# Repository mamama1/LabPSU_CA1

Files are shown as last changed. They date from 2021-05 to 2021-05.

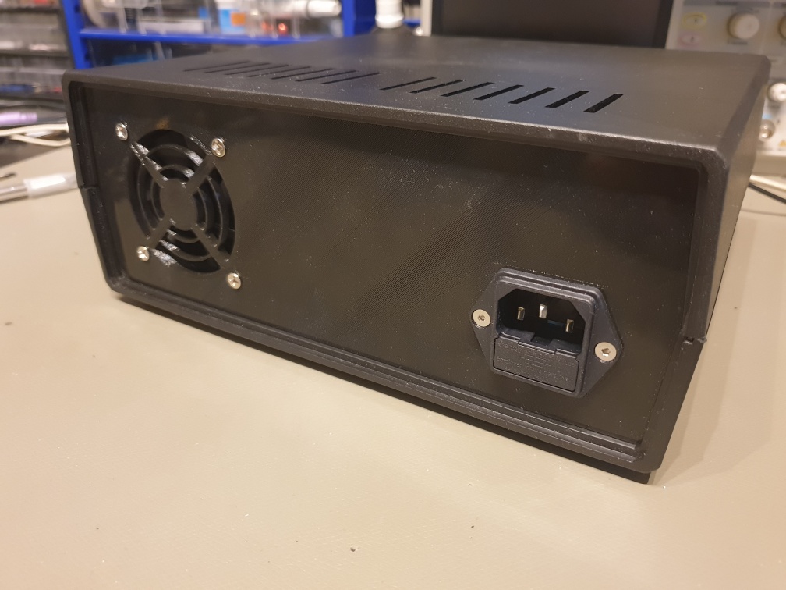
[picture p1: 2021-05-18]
photo_back.jpg

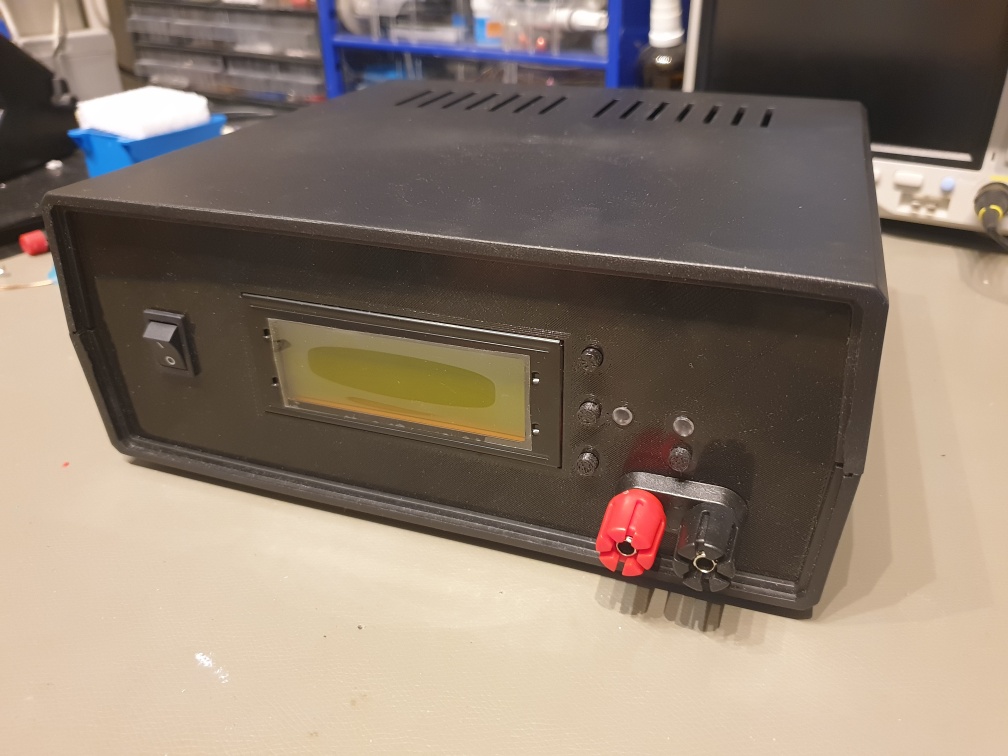
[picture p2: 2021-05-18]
photo_front.jpg

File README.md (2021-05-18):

# LabPSU_CA1
"CheapAss 1" Atmega 1284p controlled LabPSU with basic functionality like CV and CC mode

Welcome to my "CheapAss 1" Lab PSU project, which is based on a TIP3055 power transistor and an Atmega 1284p microcontroller.<br /><br />

Specs:<br />
0 - 24V output voltage in 100 mV steps (CV mode)<br />
0 - 1A output current in 1 mA steps (CC mode)<br />
Around 1% accuracy<br />
Dual 12 Bit DAC (MCP4922)<br />
Precision 4.096V voltage reference for the DAC and Atmega-integrated ADC (MCP1541)<br />
High-side current measurement using the MAX4080F IC<br />
LM324 Quad opamp and LM358 Dual opamp<br />
Low Ripple, Low Noise<br />
One Board solution (transformer onboard)<br />
Front panel for display, buttons, LED and piezo buzzer mounting

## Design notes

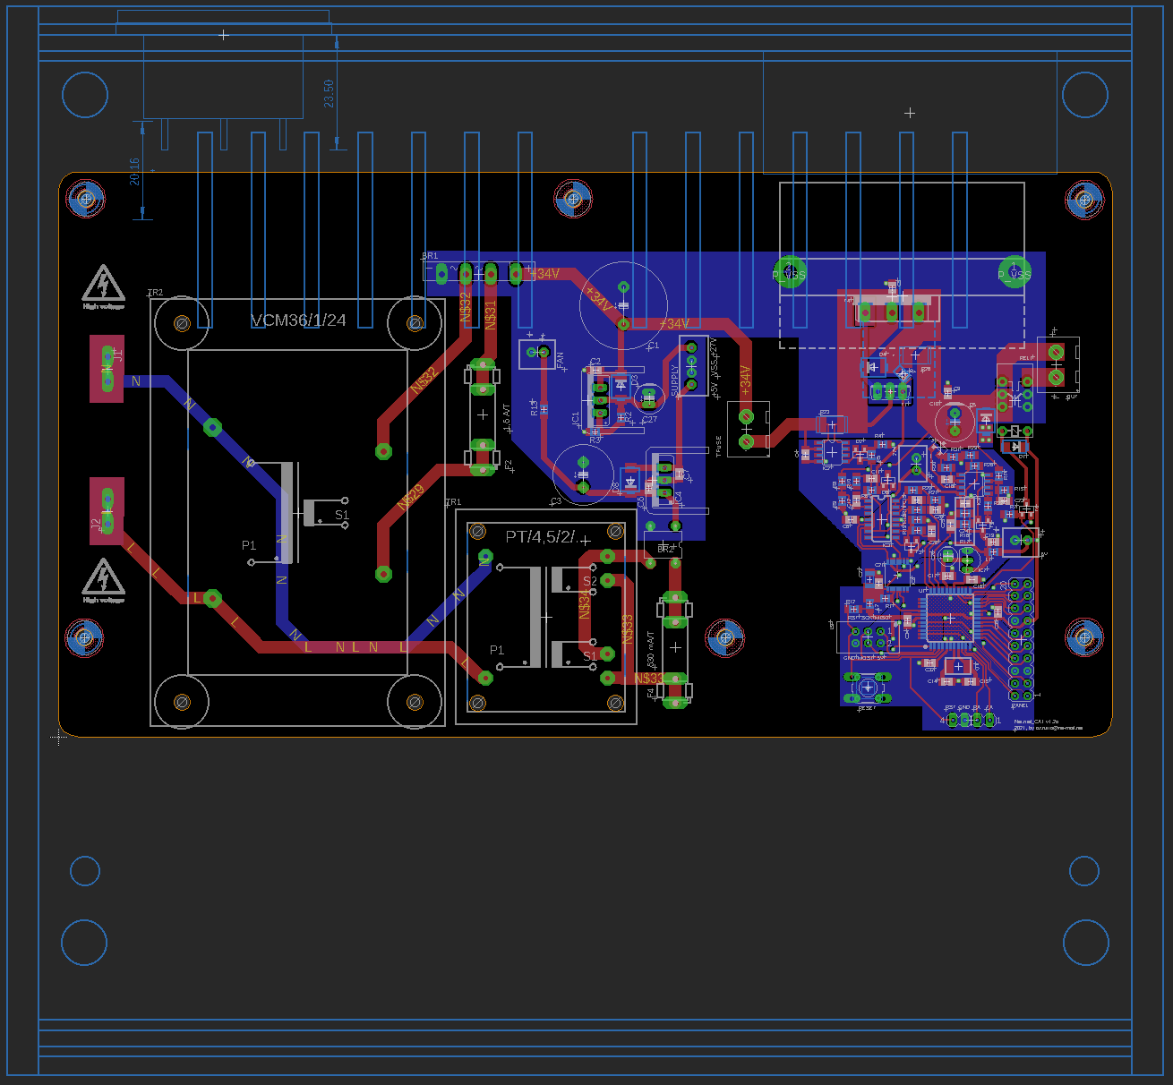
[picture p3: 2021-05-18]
Mainboard/preview.PNG

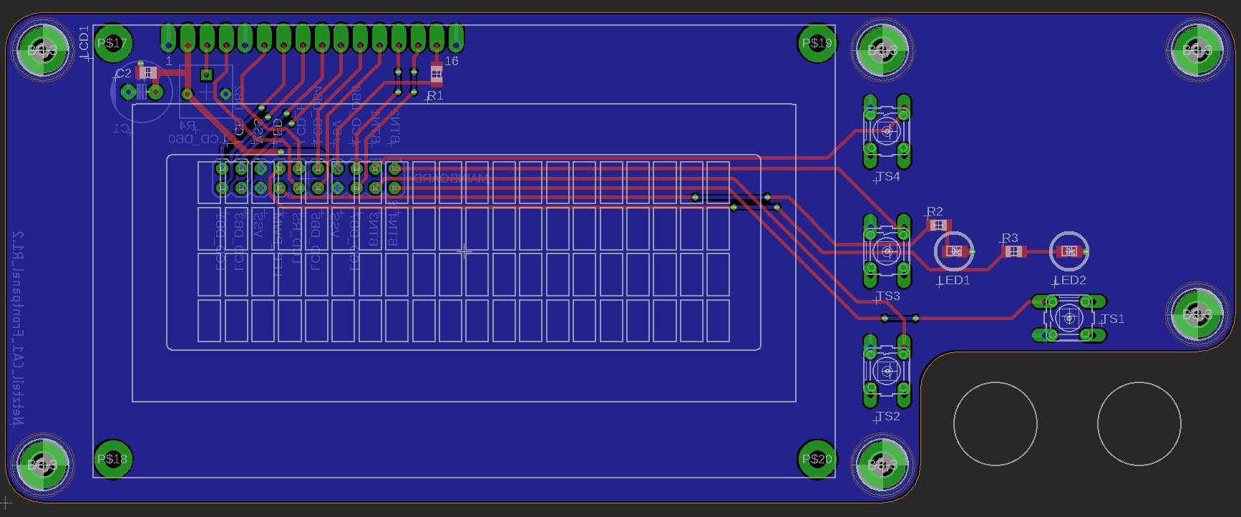
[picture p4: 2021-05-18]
Frontpanel/preview.PNG

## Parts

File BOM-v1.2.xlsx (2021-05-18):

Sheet: BOM-Mainboard
Qty | Value | Parts | OC_CONRAD | OC_CONRAD_ADD | OC_DIGIKEY | OC_MOUSER | OC_MOUSER_ADD | OC_MOUSER_ALT | OC_MOUSER_ALT2_OLD | OC_MOUSER_ALT_OLD | OC_MOUSER_OLD | OC_RS | OC_RS_ADD | OC_RS_ADD2 | REMARKS
1 |  | FAN |  |  | 455-1704-ND |  | 369-MF60251V21UA99 |  |  |  |  |  |  |  | JST-PH Buchse und Lüfter
2 |  | 5V, 27V |  |  | 455-1704-ND
1 |  | SUPPLY |  |  | 455-1706-ND
1 |  | OUT |  |  |  | 710-691311500002 | 565-6883 |  |  |  |  |  |  |  | Printklemme und Schraubklemme für Frontpanel
1 |  | TFUSE |  |  |  | 710-691311500002 |  |  |  |  |  |  | 712-7284 |  | Printklemme und Thermosicherung
1 |  | SERIAL |  |  |  | 200-TSW10407TS
1 |  | PANEL |  |  |  | 200-TSW10707FD |  |  |  |  |  | 289-9896 | 832-3516 |  | Stiftleiste, IDC Stecker und IDC Flachbandkabel
1 |  | ISP |  |  |  | 200-TSW10307TD
1 |  | RESET |  |  |  | 653-B3F-1022
1 | 0.1R 5% 3W 100ppm | R26 |  |  |  | 652-CRA2512FZR100ELF
1 | 0.2R 1% 50ppm | R23 |  |  |  | 756-LRMAP2512R20FT4
1 | 1 A/T | F4 |  |  |  | 693-0751.0110
1 | 1,6 A/T | F2 |  |  |  | 693-0751.0110
1 | 100R 1% 1/4W | R13 |  |  |  | 660-RK73H2ATTD75R0F
9 | 100n/16V | C16, C17, C19, C21, C23, C28, C32, C33, C34 |  |  |  | 810-C2012X7R2A104K
6 | 100n/50V | C2, C4, C7, C8, C9, C24 |  |  |  | 810-C2012X7R2A104K
1 | 100µ/50V | C10 |  |  |  | 667-EEU-FR1H101
1 | 10R 0.5% 25 ppm 1/10W | R31 |  |  |  | 660-RN732ATTD10R0D25 |  | 279-2-1625868-7
5 | 10k 5% 1/10W | R1, R5, R7, R12, R22 |  |  |  | 652-CR0805-JW-103ELF
2 | 10n/16V | C25, C26 |  |  |  | 80-C0805C103K1R
1 | 10n/50V | C11 |  |  |  | 80-C0805C103K1R
1 | 10µ/16V | C20 |  |  |  | 647-USV1C100MFD1TP
1 | 10µ/16V | C22 |  |  |  | 963-TMK316AB7106KL-T
1 | 12k 0.5% 1/10W 25ppm | R8 |  |  |  | 754-RR1220P-123D
3 | 14.7k 0.5% 1/10W 25ppm | R14, R20, R28 |  |  |  | 754-RR1220P-1472D-M |  |  |  |  | 754-RR1220P-123D | 708-6470
1 | 16MHz | Q1 |  |  |  | 717-7A-16.000MAAJ-T
1 | 178R 0.5% 1/10W 25ppm | R29 |  |  |  | 754-RR1220P-1780D-M |  |  | 667-ERA-6AEB1470V | 754-RR1220P-151D | 754-RR1220P-1470D-M | 708-9340
1 | 1k 0.5% 50 ppm 1/10W | R30 |  |  |  | 754-RR1220P-102D
2 | 1n/50V | C13, C18 |  |  |  | 603-CC805KRX7R0BB102
2 | 2.8k 0.5% 1/10W 25ppm | R15, R21 |  |  |  | 754-RR1220P-2801D-M |  |  |  |  | 754-RR1220P-242D | 708-6250
1 | 2200µ/25V | C3 |  |  |  | 667-EEU-FS1E222
3 | 22pF/50V C0G | C12, C14, C15 |  |  |  | 603-CC805JRNPO9BN220
1 | 240R 1% 1/10W | R2 |  |  |  | 652-CR0805FX-2400ELF
1 | 3300µ/50V | C1 |  |  |  | 667-EEU-HD1H332 |  | 647-UVZ1H332MHD
2 | 330n/50V | C5, C6 |  |  |  | 80-C0805C334K5RECTU
1 | 3k 0.5% 1/10W 25ppm | R9 |  |  |  | 754-RR1220P-302D
6 | 4.7k 5% 1/10W | R4, R11, R16, R17, R18, R19 |  |  |  | 652-CR0805-JW-472ELF
1 | 47k 1% 1/10W | R10 |  |  |  | 652-CR0805FX-4702ELF
1 | 47µ/50V | C27 |  |  |  | 667-EEU-FR1H470
1 | 4k7 1% 1/10W | R6 |  |  |  | 652-CR0805FX-1001ELF
1 | 5k1 1% 1/10W | R3 |  |  |  | 652-CR0805FX-5101ELF
1 | 7805TV | IC4 |  |  |  | 511-L7805CV
1 | ATMEGA1284P-AU-TQFP44 | U1 |  |  |  | 556-ATMEGA1284P-AU
2 | BAT54FILMY | D2, D6 |  |  |  | 511-BAT54FILMY
2 | BC847ALT1G | T2, T3 |  |  |  | 863-BC847ALT1G
1 | BD139 | T1 |  |  |  | 511-BD139-10
4 | CGRB307-G | D3, D4, D5, D8 |  |  |  | 750-CGRB307-G
1 | CR201-50VE | HS1 |  |  |  | 588-CR201-50VE | 567-CD-02-05-247-N |  |  |  |  |  |  |  | Kühlkörper und Silpad
2 | D01S | HS2, HS3 |  |  |  | 532-576802B00
1 | DF04M | BR2 |  |  |  | 621-DF04M |  | 512-DF04M
2 | FASTON4.8X0.8 | J1, J2 | 736079 | 1022092 |  |  |  |  |  |  |  |  |  |  | Flachsteckhülsen und Lötstifte
1 | GBU4 | BR1 |  |  |  | 833-GBU4JL-BP
1 | LM317T | IC1 |  |  |  | 511-LM317T
1 | LM324 | IC3 |  |  |  | 595-LM324ADR
1 | LM358 | IC9 |  |  |  | 595-LM358ADR
1 | MAX4080F | IC2 |  |  |  | 700-MAX4080FASA
1 | MCP1541 | IC7 |  |  |  | 579-MCP1541ITO
1 | MCP4922 | IC8 |  |  |  | 579-MCP4922T-E/ST
1 | MOUNT-HOLE3.2 | H2 |  |  |  |  |  |  |  |  |  | 184-2740 | 291-379 | 161-3689 | Nylonschraube, Nylonmutter und Kunststoff-Abstandshalter
5 | MOUNT-HOLE3.2 | H1, H5, H6, H8, H9 |  |  |  |  |  |  |  |  |  | 546-5604
2 | MPZ2012S601AT000 | L1, L2 |  |  |  | 810-MPZ2012S601AT000
2 | PMV130ENEAR | T5, T6 |  |  |  | 771-PMV130ENEAR
1 | PT 4.5/2/8 | TR1 |  |  |  |  |  |  |  |  |  | 201-8463 | 546-5604 |  | Trafo und selbstschneidende Schrauben
1 | S1K | D1 |  |  |  | 512-S1K
1 | SS1FN6-M3/H | D7 |  |  |  | 78-SS1FN6-M3/H
1 | TIP3055 | T4 |  |  |  | 863-TIP3055G
1 | TX2-5V | REL1 |  |  |  | 769-TX2-5V
1 | VCM 36/1/24 | TR2 |  |  |  |  |  |  |  |  |  | 732-0506

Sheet: BOM-Frontpanel
Qty | Value | Parts | OC_MOUSER | OC_MOUSER_ADD | OC_RS | SCREW | REMARKS
1 |  | MAINBOARD | 200-TSW10707FD |  | 832-3516 |  | Stiftleiste und IDC Stecker
4 |  | TS1, TS2, TS3, TS4 | 653-B3F-1022
1 | 100n/16V | C2 | 810-C2012X7R2A104K
1 | 100µ/50V | C1 | 667-EEU-FR1H101
1 | 10K | R4 | 652-3362P-1-103LF
1 | 2.2k 1% 1/10W | R3 | 652-CR0805FX-2201ELF
1 | 330R 5% 1/10W | R1 | 652-CR0805FX-3300ELF
1 | 390R 1% 1/10W | R2 | 652-CR0805FX-3900ELF
1 | G | LED2 | 710-150080GS75000 | 593-LFC025CTP |  |  | LED und Lightpipe
1 | LCD | LCD1 | 992-LCD-20X4Y
6 | MOUNT-PAD-ROUND3.3 | H1, H2, H3, H4, H5, H6 |  |  |  | M3x5
1 | Y | LED1 | 710-150080YS75000 | 593-LFC025CTP |  |  | LED und Lightpipe
1 | ROCKER SWITCH | AC SWITCH | 979-1858.1103

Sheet: BOM-Various
Qty | Value | Parts | OC_MOUSER | OC_MOUSER_ADD | OC_RS | SCREW | REMARKS
1 | Case KRADEX Z17W |  |  |  |  |  | https://www.kradex.de/product/gehaeuse_mit_seitenpaneelen/z17
1 | IEC Socket /w fuse holder |  | 693-6200.2200
1 | 200 mA/T 5x20 fuse
1 | 1.6 A/T 5x20 fuse
1 | 630 mA/T 5x20 fuse
1 | 60cm AWG14/1,5mm2 wire black
1 | 60cm AWG14/1,5mm2 wire red
6 | M3x5mm machine screws |  |  |  |  |  | Frontpanel
4 | M3x8mm machine screws |  |  |  |  |  | Main transformer
4 | M3 self-securing nuts |  |  |  |  |  | Main transformer
1 | Thermal fuse ~90°C |  |  |  | 712-7284
1 | KNIPEX Crimpzange (240 mm) 97 22 240 |  |  |  |  |  | Crimpzange für Flachsteckhülsen

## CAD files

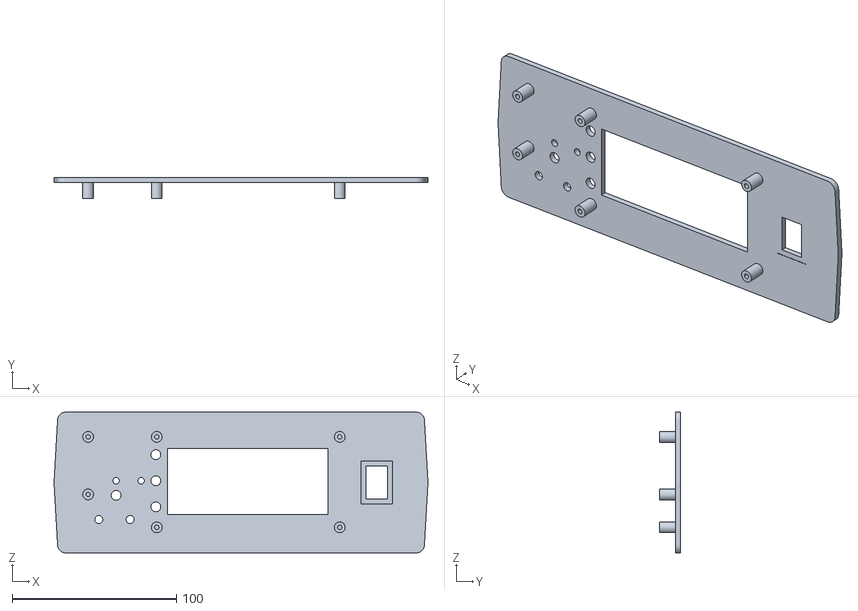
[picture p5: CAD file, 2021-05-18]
STL/front_panel_CA1_R1.2_565-6883.stl
227.4 x 13.0 x 85.6

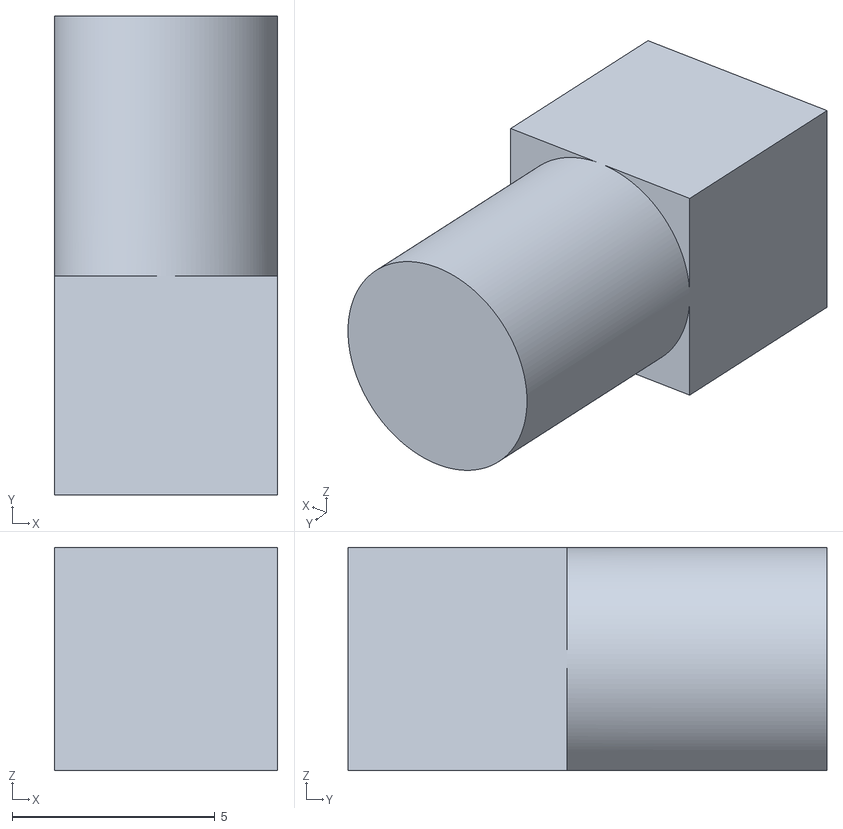
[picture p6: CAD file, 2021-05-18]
STL/button.stl
5.50 x 11.8 x 5.50

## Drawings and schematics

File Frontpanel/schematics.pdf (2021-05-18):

# Rocker Switch: 1858.1103

## MAINBOARD

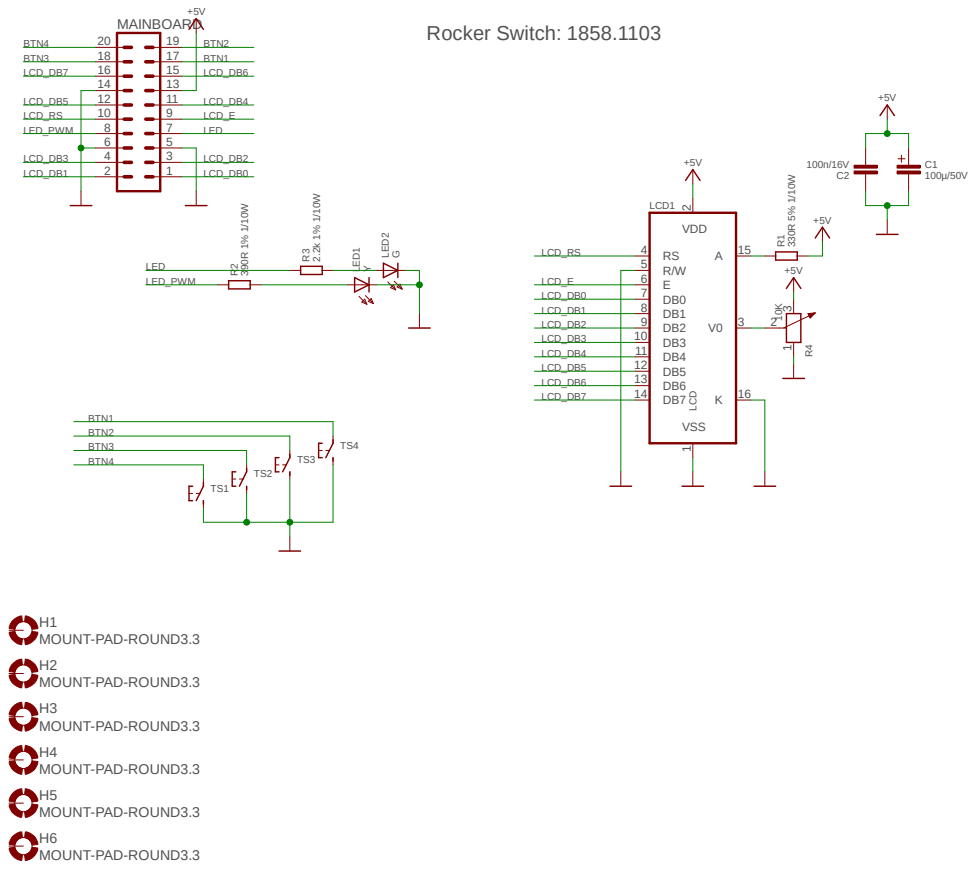
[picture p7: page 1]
VDD; MOUNT-PAD-ROUND3.3; LCD; LCD1 2 1; TS4LED¹ R³; LED² R²; LED; LCD_E; LCD_DB4; BTN1; BTN2; LED_PWM; LCD_RS; LCD_DB5; LCD_DB7; BTN3; BTN4; LCD_DB6; LCD_DB1; LCD_DB0; LCD_DB2; LCD_DB3

VSS MOUNT-PAD-ROUND3.3

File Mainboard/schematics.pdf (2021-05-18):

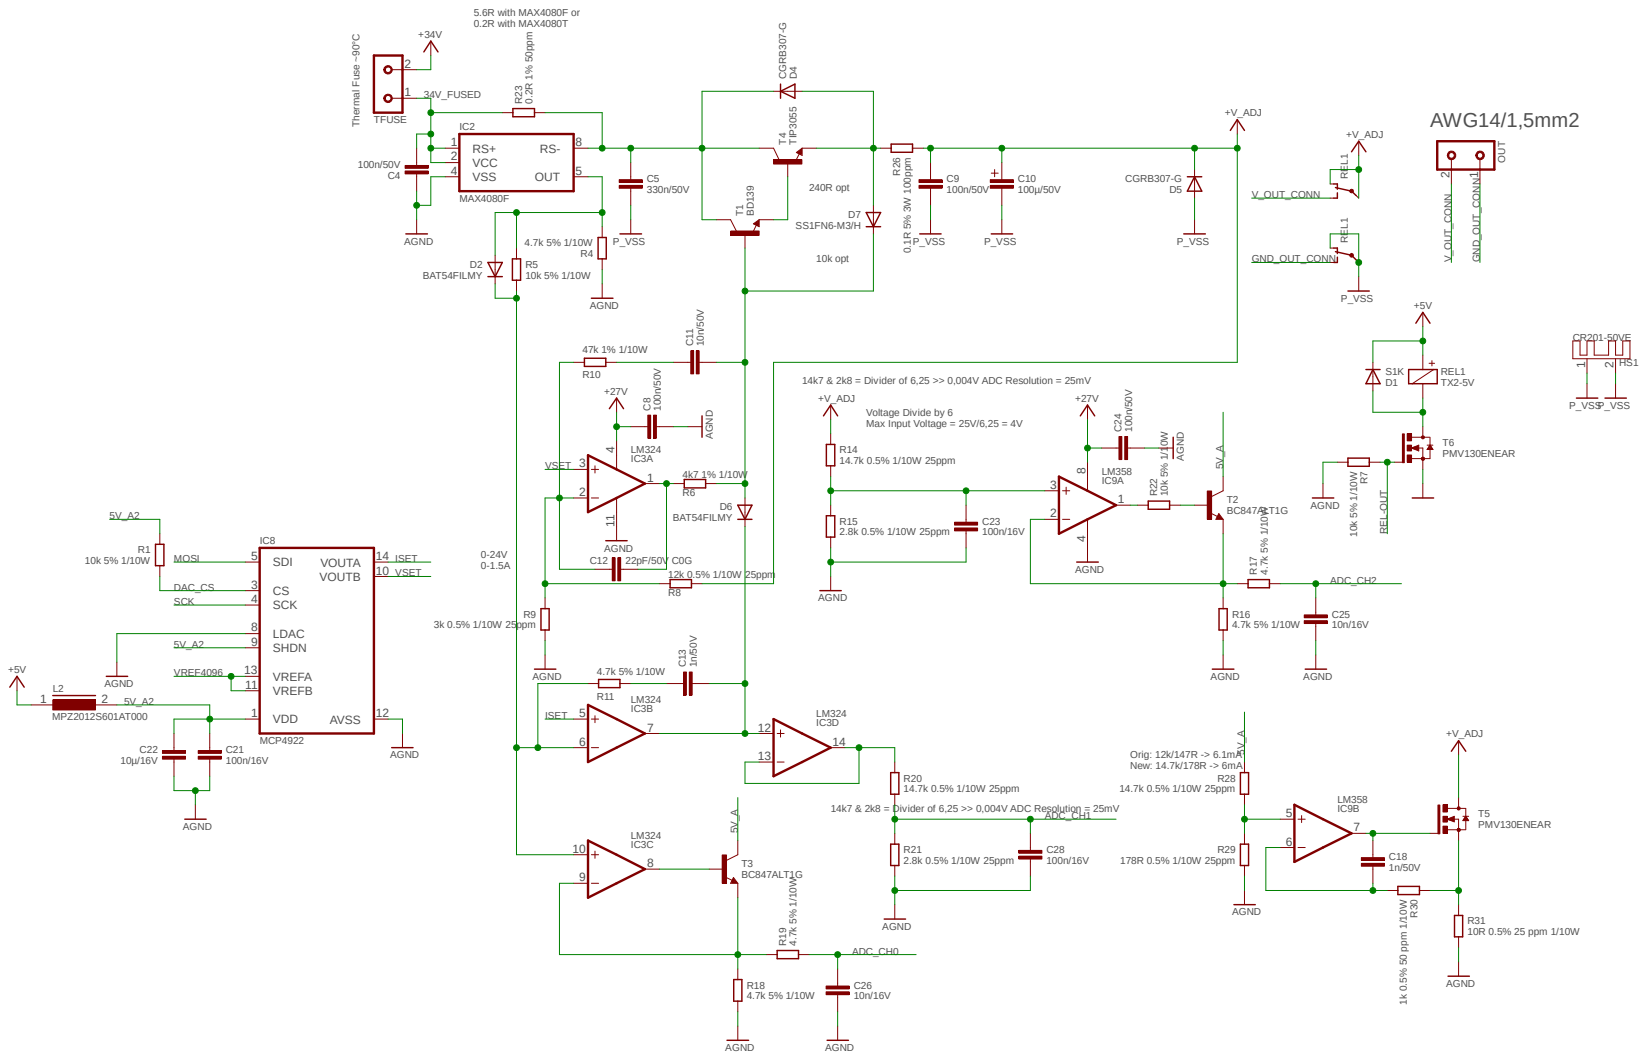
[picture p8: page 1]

14k7 & 2k8 = Divider of 6,25 >> 0,004V ADC Resolution = 25mV
+V_ADJ

+34V | MOUNT-HOLE3.2 | MOUNT-HOLE3.2

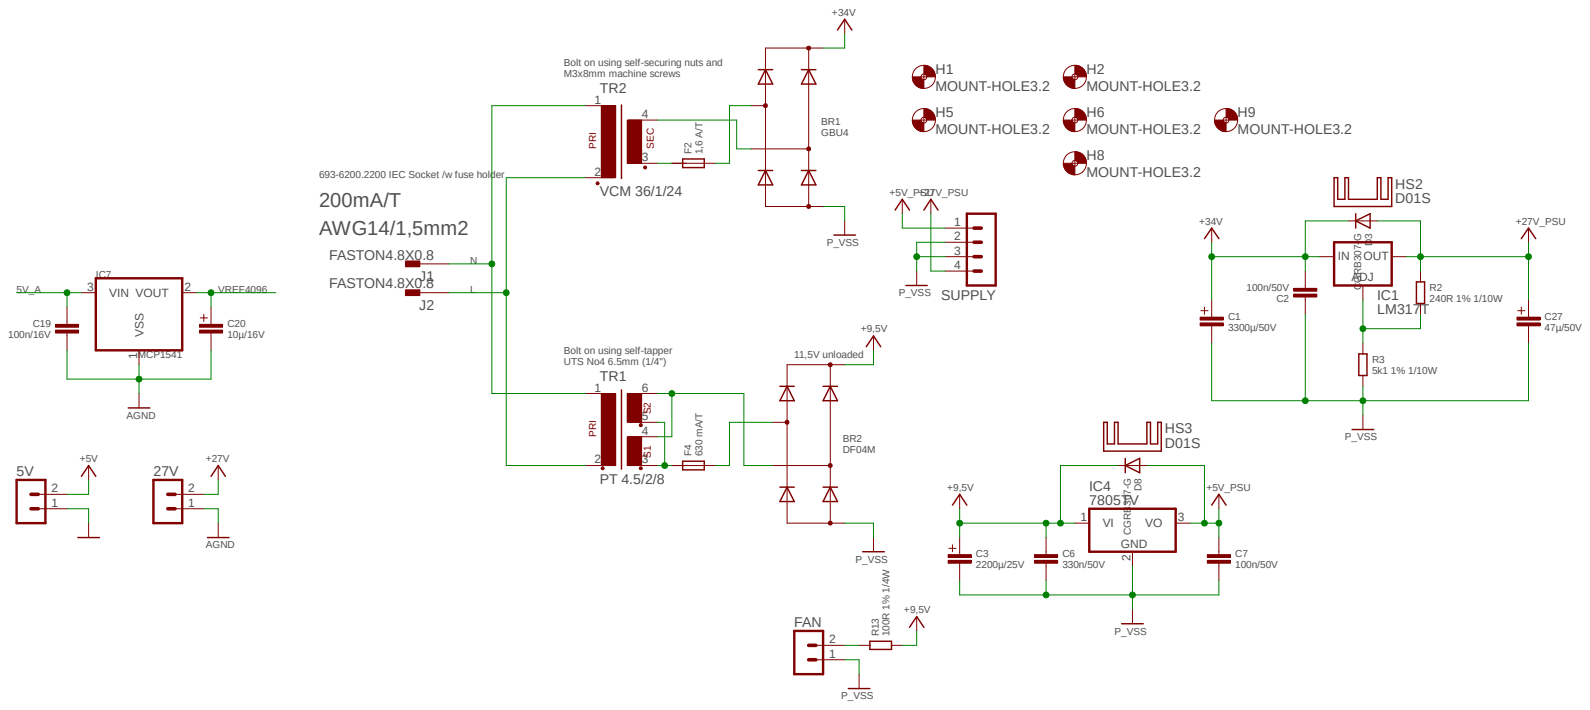
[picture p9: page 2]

693-6200.2200 IEC Socket /w fuse holder

Bolt on using self-tapper

## PANEL 20 ISP

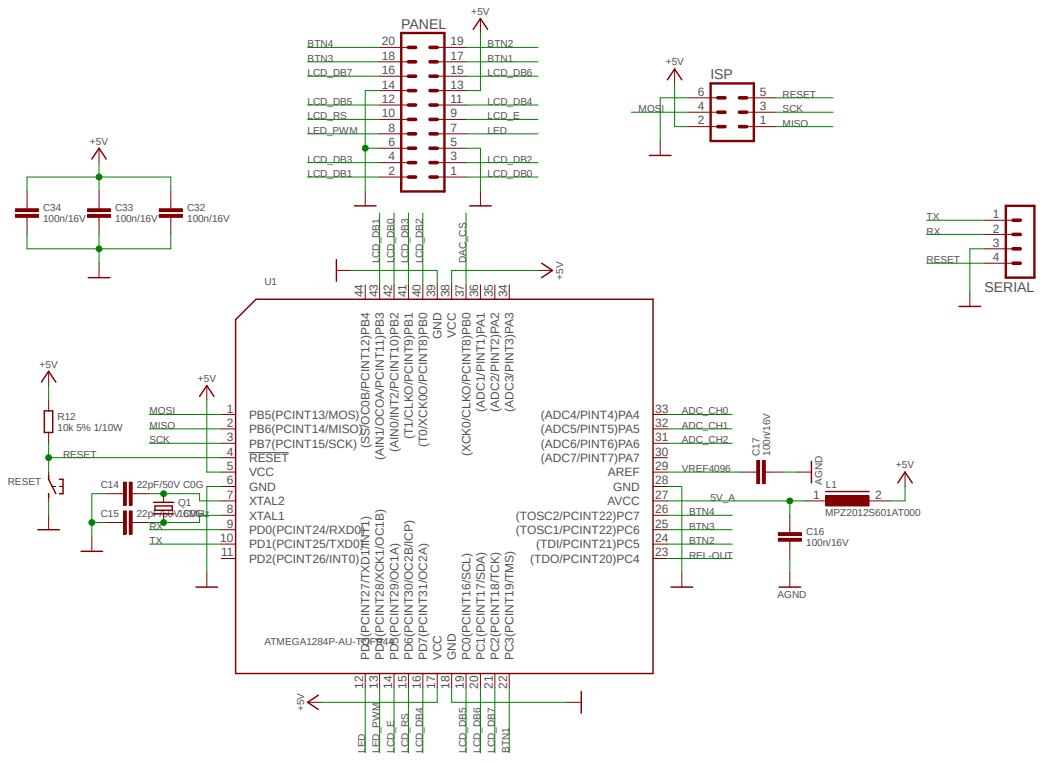
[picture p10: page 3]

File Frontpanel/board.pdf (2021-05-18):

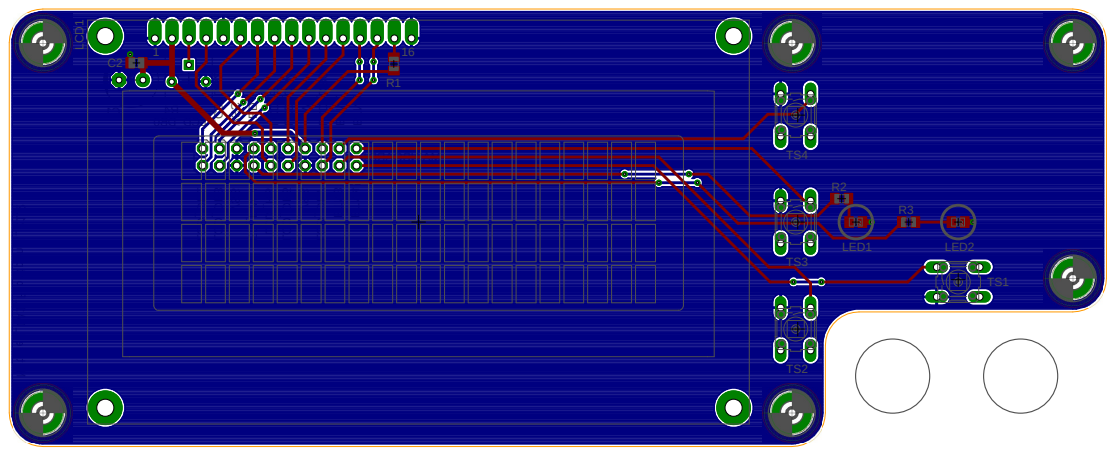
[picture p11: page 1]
LED LCD_E LCD_DB4 +5V LCD_DB6 BTN1 BTN2 BTN3 BTN4 LCD_DB7 VSS LCD_DB5 LCD_RS LED_PWM; LED1; LED2

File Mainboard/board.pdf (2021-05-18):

# S1 ²³.50

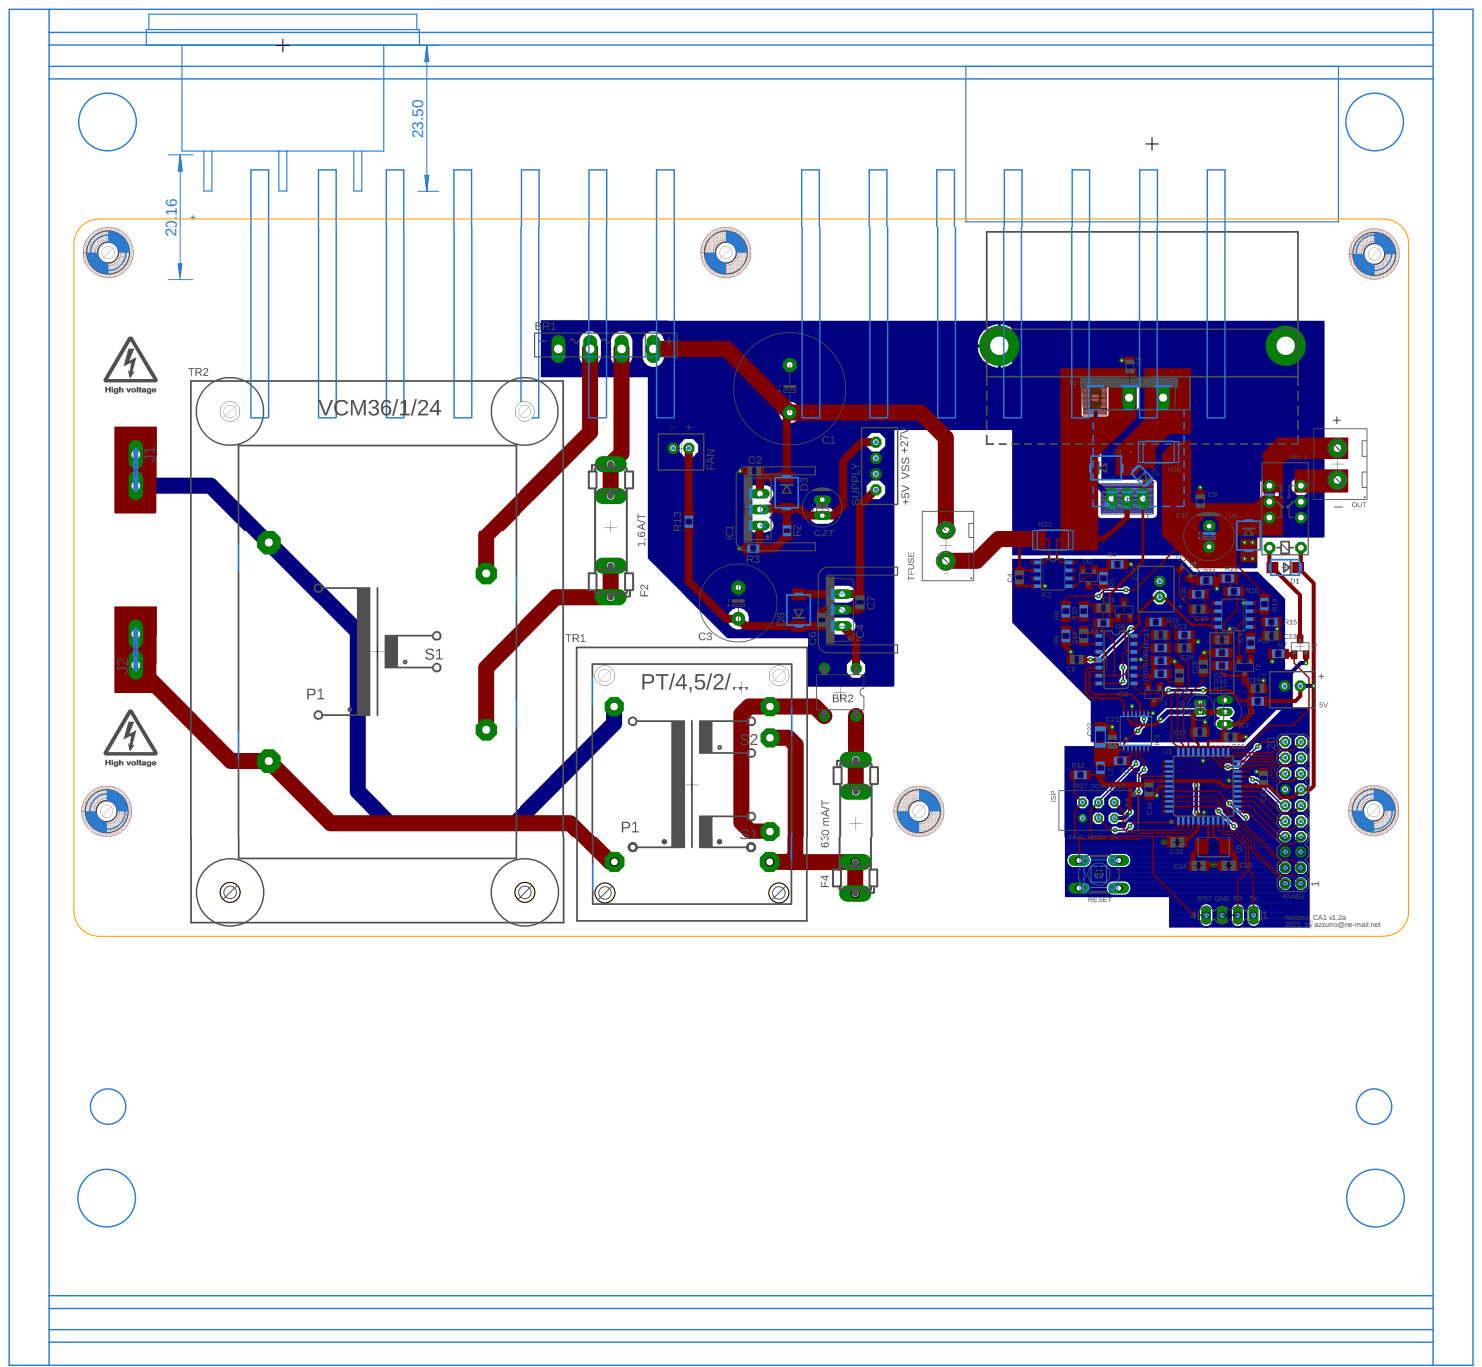
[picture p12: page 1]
GND MOSI; RESET; PANEL F4

RST GND RX TX

Netzteil_CA1 v1.2a
2021, by azzurro@ne-mail.net

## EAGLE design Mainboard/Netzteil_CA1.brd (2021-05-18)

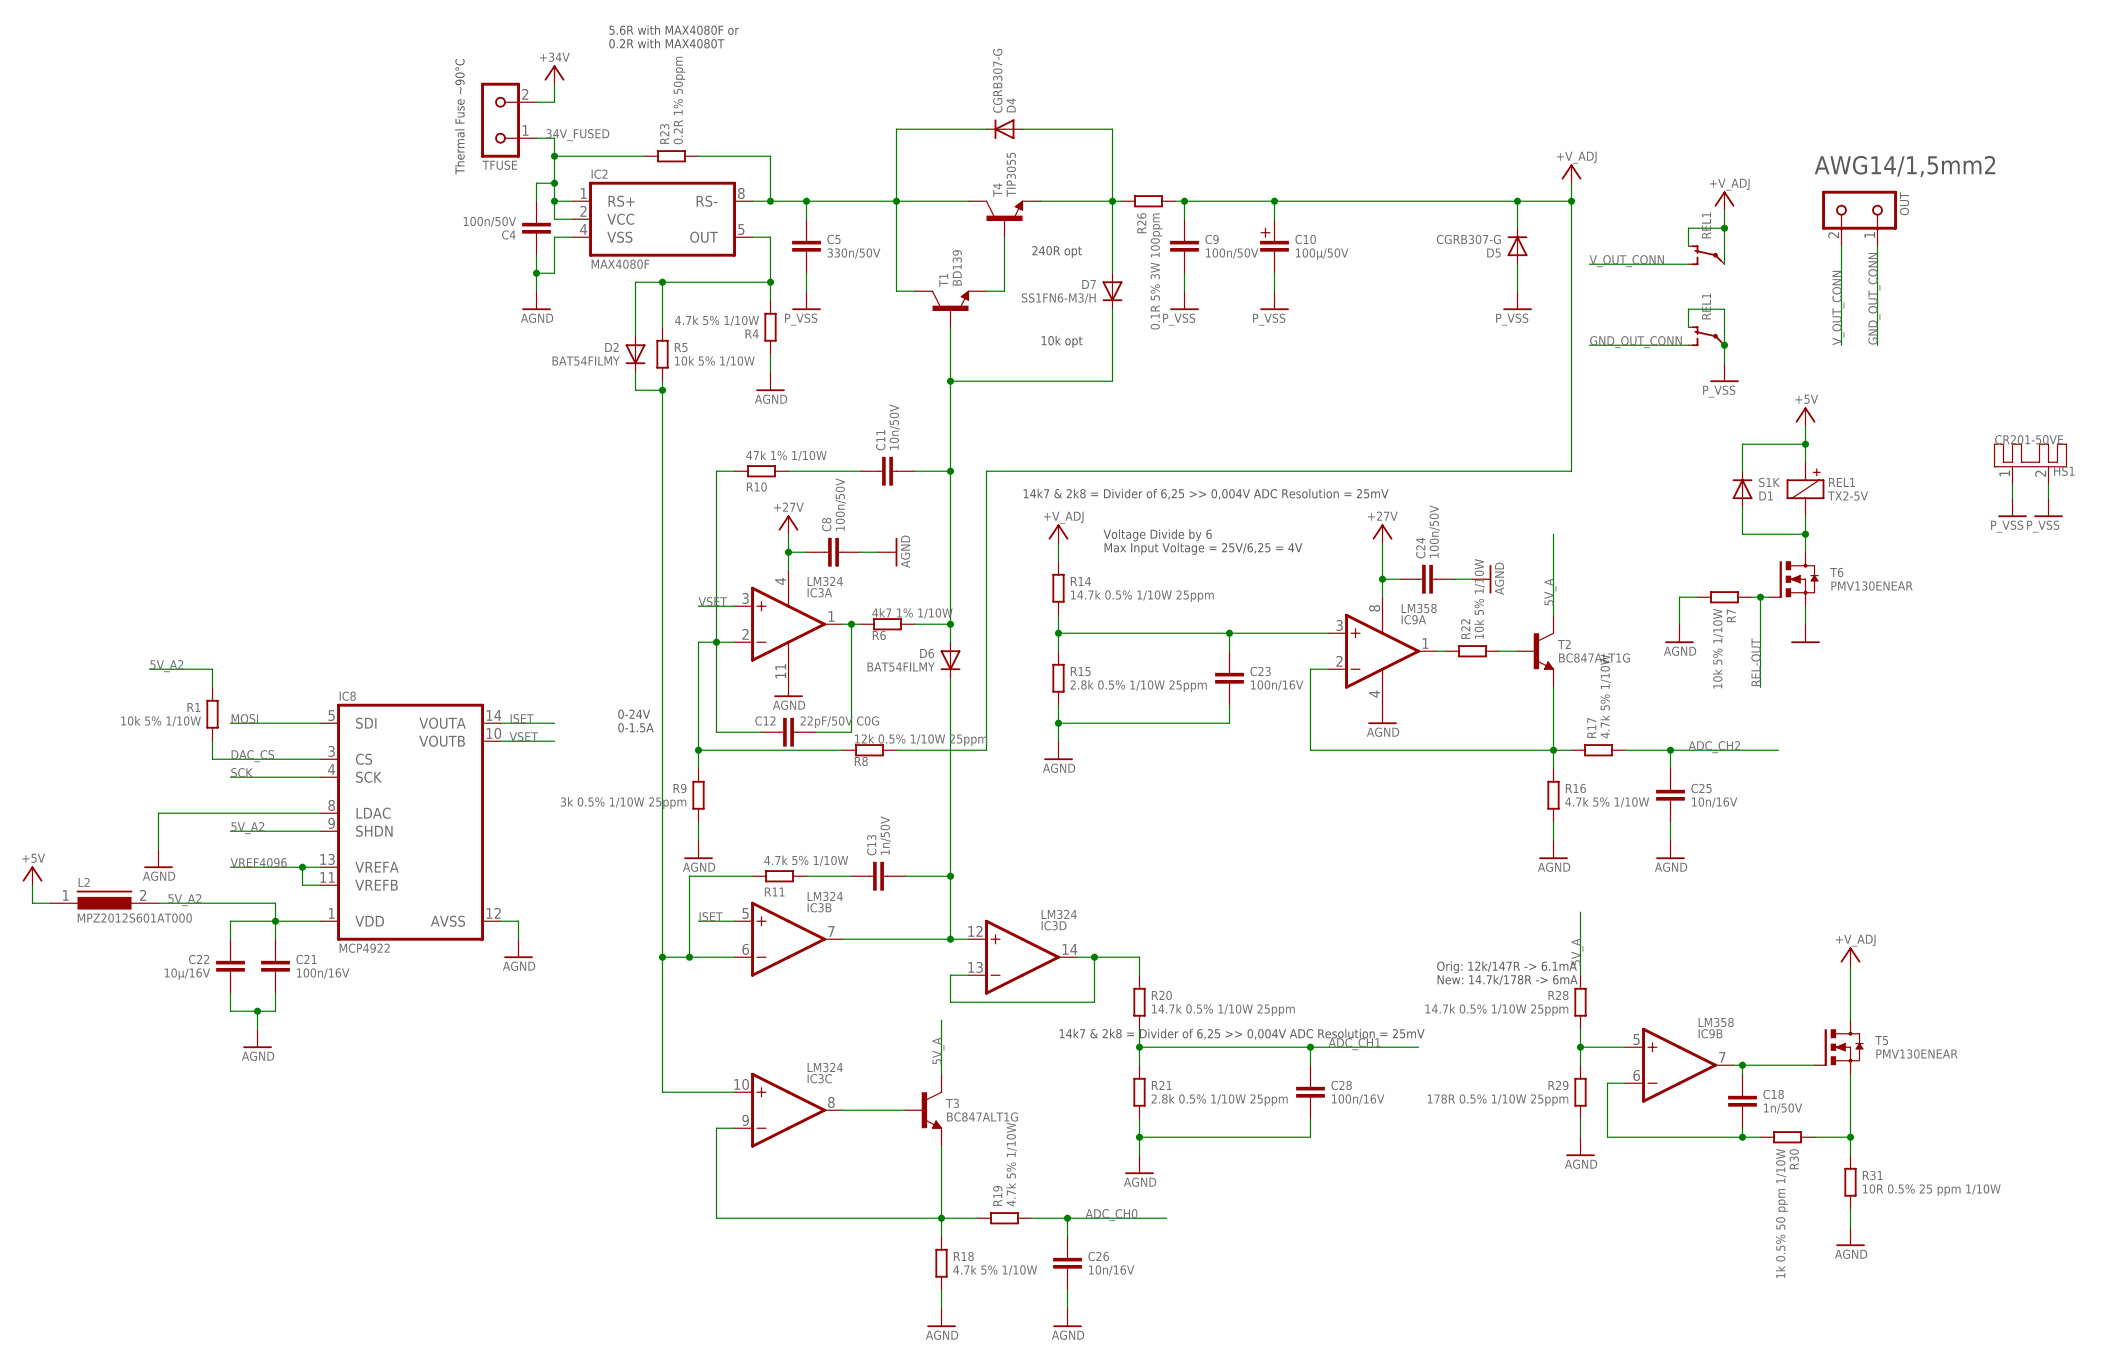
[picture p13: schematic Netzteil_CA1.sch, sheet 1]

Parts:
C4, C8, C9, C24: 100n/50V; 0805
C5: 330n/50V; 0805
C10: 100µ/50V; C+/3.5/8
C11: 10n/50V; 0805
C12: 22pF/50V C0G; 0805
C13, C18: 1n/50V; 0805
C21, C23, C28: 100n/16V; 0805
C22: 10µ/16V; 1206
C25, C26: 10n/16V; 0805
D1: S1K; DO214AC
D2, D6: BAT54FILMY; SOT23
D4, D5: CGRB307-G; DO214AA-CGRB307-G
D7: SS1FN6-M3/H; DO219AB-2
HS1: CR201-50VE; CR201-50
IC2: MAX4080F; SOP8
IC3: LM324; SO14
IC8: MCP4922; TSSOP14
IC9: LM358; SOP8
L2: MPZ2012S601AT000; C0805K
OUT: KL2691311500002; KL2-691311500002
R1, R5, R7, R22: 10k 5% 1/10W; C0805K
R4, R11, R16, R17, R18, R19: 4.7k 5% 1/10W; C0805K
R6: 4k7 1% 1/10W; C0805K
R8: 12k 0.5% 1/10W 25ppm; C0805K
R9: 3k 0.5% 1/10W 25ppm; C0805K
R10: 47k 1% 1/10W; C0805K
R14, R20, R28: 14.7k 0.5% 1/10W 25ppm; C0805K
R15, R21: 2.8k 0.5% 1/10W 25ppm; C0805K
R23: 0.2R 1% 50ppm; LRMAP2512
R26: 0.1R 5% 3W 100ppm; YAG_PT2512
R29: 178R 0.5% 1/10W 25ppm; C0805K
R30: 1k 0.5% 50 ppm 1/10W; C0805K
R31: 10R 0.5% 25 ppm 1/10W; C0805K
REL1: TX2-5V; REL-TX2
T1: BD139; TO126
T2, T3: BC847ALT1G; SOT23-BEC
T4: TIP3055; TOP3AV
T5, T6: PMV130ENEAR; SOT23
TFUSE: KL2691311500002; KL2-691311500002

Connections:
5V_A: R28.1, T2.C, T3.C; also elsewhere on the board
5V_A2: C21.1, C22.1, IC8.1 (VDD), IC8.9 (SHDN), L2.2, R1.1
34V_FUSED: C4.2, IC2.1 (RS+), IC2.2 (VCC), R23.1, TFUSE.1
+5V: D1.C, L2.1, REL1.+; also elsewhere on the board
+27V: C8.1, C24.1, IC3.4 (V+), IC9.8 (V+); also elsewhere on the board
+34V: TFUSE.2; also elsewhere on the board
+V_ADJ: C9.1, C10.+, D5.C, R8.1, R14.1, R26.2, REL1.O1 (O), REL1.P1, T5.3 (D)
ADC_CH0: C26.1, R19.2; also elsewhere on the board
ADC_CH1: C28.1, R20.2, R21.1; also elsewhere on the board
ADC_CH2: C25.1, R17.2; also elsewhere on the board
AGND: C4.1, C8.2, C21.2, C22.2, C23.2, C24.2, C25.2, C26.2, C28.2, IC2.4 (VSS), IC3.11 (V-), IC8.8 (LDAC), IC8.12 (AVSS), IC9.4 (V-), R4.1, R7.2, R9.2, R15.2, R16.2, R18.2, R21.2, R29.2, R31.2; also elsewhere on the board
DAC_CS: IC8.3 (CS), R1.2; also elsewhere on the board
GND_OUT_CONN: OUT.1, REL1.S2 (S)
ISET: IC3.5 (+IN), IC8.14 (VOUTA)
MOSI: IC8.5 (SDI); also elsewhere on the board
unnamed: C5.1, D4.C, IC2.8 (RS-), R23.2, T1.2 (C), T4.C
unnamed: D2.1 (A), IC2.5 (OUT), R4.2, R5.1
unnamed: D2.3 (C), IC3.6 (-IN), IC3.10 (+IN), R5.2, R11.2
unnamed: C12.2, IC3.1 (OUT), R6.2
unnamed: C11.2, D6.1 (A), D7.C, R6.1, T1.3 (B)
unnamed: C11.1, R10.1
unnamed: C13.2, D6.3 (C), IC3.7 (OUT), IC3.12 (+IN)
unnamed: IC3.13 (-IN), IC3.14 (OUT), R20.1
unnamed: C13.1, R11.1
unnamed: D1.A, REL1.-, T6.3 (D)
unnamed: IC9.1 (OUT), R22.1
unnamed: C23.1, IC9.3 (+IN), R14.2, R15.1
unnamed: C12.1, IC3.2 (-IN), R8.2, R9.1, R10.2
unnamed: IC9.2 (-IN), R16.1, R17.1, T2.E
unnamed: IC3.9 (-IN), R18.1, R19.1, T3.E
unnamed: R22.2, T2.B
unnamed: IC9.5 (+IN), R28.2, R29.1
unnamed: D4.A, D7.A, R26.1, T4.E
unnamed: IC3.8 (OUT), T3.B
unnamed: C18.2, IC9.6 (-IN), R30.2
unnamed: C18.1, IC9.7 (OUT), T5.1 (G)
unnamed: T1.1 (E), T4.B
unnamed: R30.1, R31.1, T5.2 (S)
P_VSS: C5.2, C9.2, C10.-, D5.A, HS1.1, HS1.2, REL1.O2 (O), REL1.P2; also elsewhere on the board
REL-OUT: R7.1, T6.1 (G); also elsewhere on the board
SCK: IC8.4 (SCK); also elsewhere on the board
VREF4096: IC8.11 (VREFB), IC8.13 (VREFA); also elsewhere on the board
VSET: IC3.3 (+IN), IC8.10 (VOUTB)
VSS: T6.2 (S); also elsewhere on the board
V_OUT_CONN: OUT.2, REL1.S1 (S)

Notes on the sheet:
Voltage Divide by 6 Max Input Voltage = 25V/6,25 = 4V
0-24V 0-1.5A
240R opt
10k opt
14k7 & 2k8 = Divider of 6,25 >> 0,004V ADC Resolution = 25mV
Orig: 12k/147R -> 6.1mA New: 14.7k/178R -> 6mA
5.6R with MAX4080F or 0.2R with MAX4080T
AWG14/1,5mm2
Thermal Fuse ~90°C

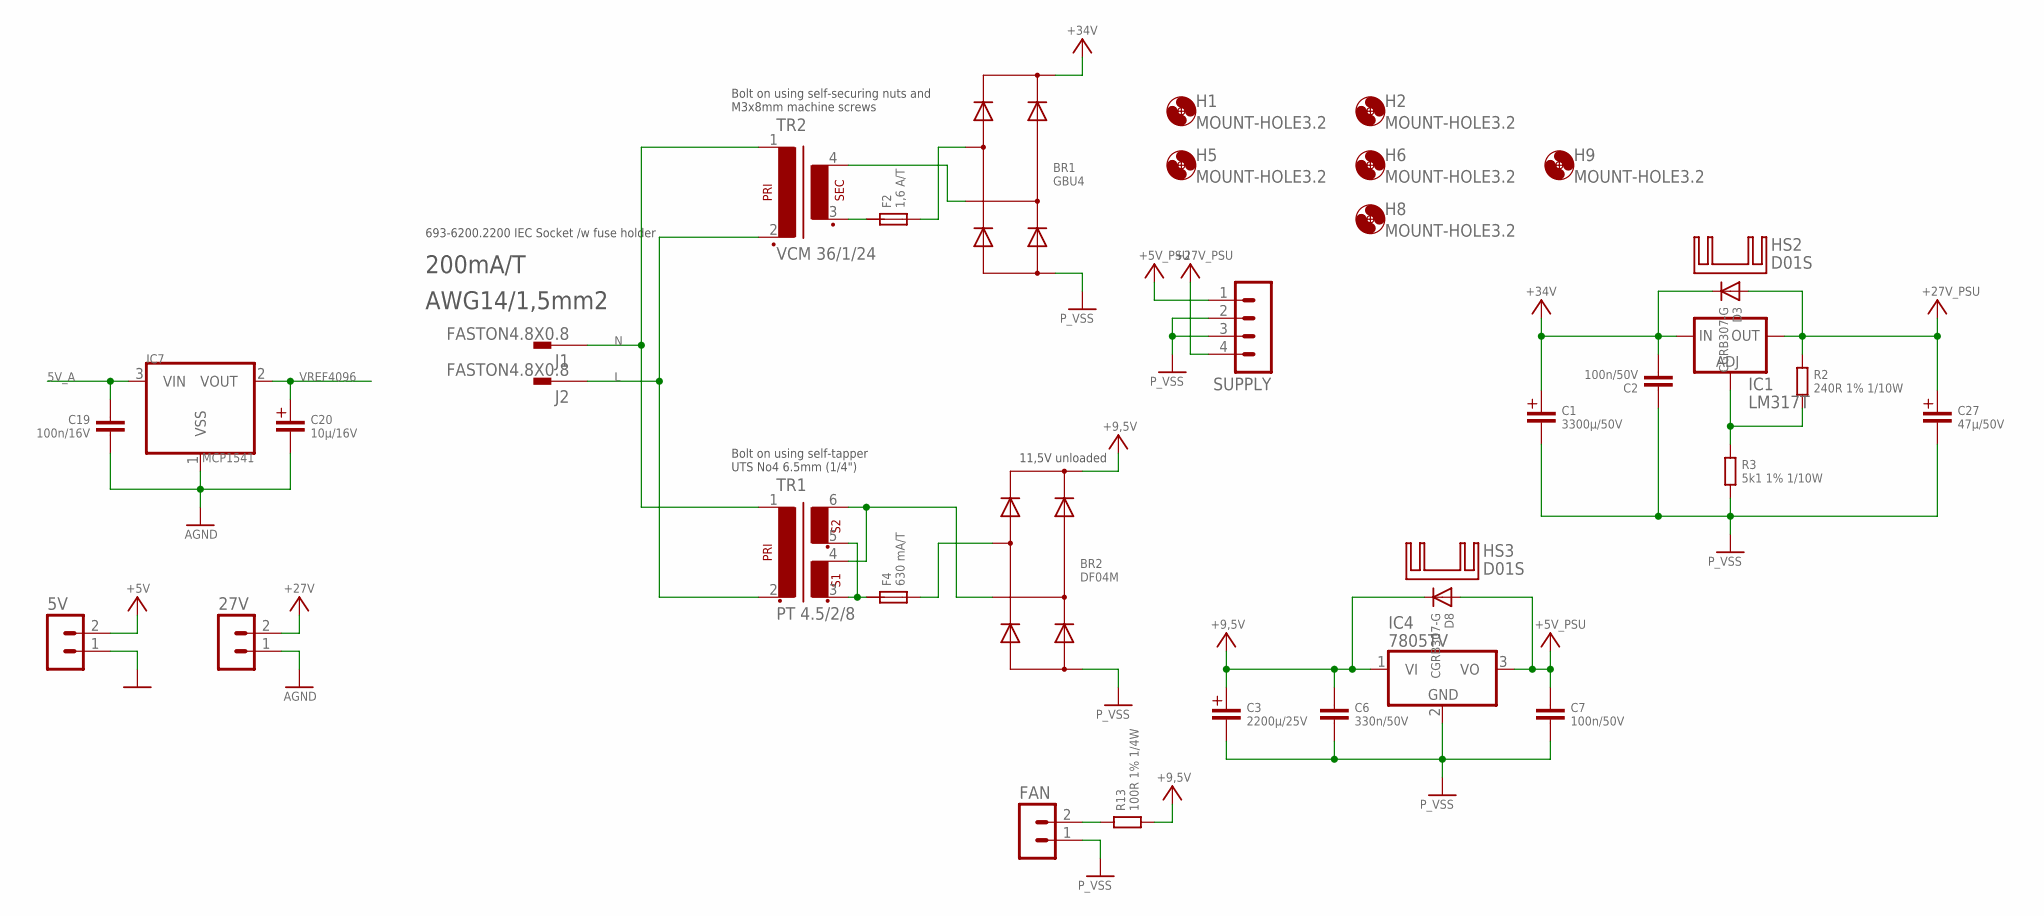
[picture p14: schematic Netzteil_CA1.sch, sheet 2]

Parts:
5V, 27V: JST-PH-2.0-2P
BR1: GBU4; GBU4S
BR2: DF04M; BR-DIL2
C1: 3300µ/50V; C+/7.5/18
C2, C7: 100n/50V; 0805
C3: 2200µ/25V; C+/5/12.5
C6: 330n/50V; 0805
C19: 100n/16V; 0805
C20: 10µ/16V; C+/1.5/4
C27: 47µ/50V; C+/2.5/6.3
D3, D8: CGRB307-G; DO214AA-CGRB307-G
F2: 1,6 A/T; F5X20
F4: 630 mA/T; F5X20
FAN: JST-PH-2.0-2P
H1, H2, H5, H6, H8, H9: MOUNT-HOLE3.2; 3,2
HS2, HS3: D01S
IC1: LM317T; 317TS
IC4: 7805TV; TO220V
IC7: MCP1541; TO92-G
J1, J2: FASTON4.8X0.8; FASTON-4.8X0.8
R2: 240R 1% 1/10W; C0805K
R3: 5k1 1% 1/10W; C0805K
R13: 100R 1% 1/4W; C0805K
SUPPLY: JST-PH-2.0-4P
TR1: PT 4.5/2/8; PT/4,5/2/..
TR2: VCM 36/1/24; VCM36/1/24

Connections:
5V_A: C19.1, IC7.3 (VIN); also elsewhere on the board
+5V: 5V.2; also elsewhere on the board
+5V_PSU: C7.1, D8.A, IC4.3 (VO), SUPPLY.1
+9,5V: BR2.DC+, C3.+, C6.1, D8.C, IC4.1 (VI), R13.2
+27V: 27V.2; also elsewhere on the board
+27V_PSU: C27.+, D3.A, IC1.2 (OUT), R2.1, SUPPLY.4
+34V: BR1.+ (DC+), C1.+, C2.2, D3.C, IC1.3 (IN); also elsewhere on the board
AGND: 27V.1, C19.2, C20.-, IC7.1 (VSS); also elsewhere on the board
L: J2.A1, J2.A2, TR1.2, TR2.2
N: J1.A1, J1.A2, TR1.1, TR2.1
unnamed: IC1.1 (ADJ), R2.2, R3.1
unnamed: BR2.AC1, F4.3 (2), F4.4 (2)
unnamed: F2.1, F2.2 (1), TR2.3 (S3)
unnamed: BR1.AC1, F2.3 (2), F2.4 (2)
unnamed: BR1.AC2, TR2.4 (S4)
unnamed: F4.1, F4.2 (1), TR1.3, TR1.5
unnamed: BR2.AC2, TR1.4, TR1.6
unnamed: FAN.2, R13.1
P_VSS: BR1.- (DC-), BR2.DC-, C1.-, C2.1, C3.-, C6.2, C7.2, C27.-, FAN.1, IC4.2 (GND), R3.2, SUPPLY.2, SUPPLY.3; also elsewhere on the board
VREF4096: C20.+, IC7.2 (VOUT); also elsewhere on the board
VSS: 5V.1; also elsewhere on the board

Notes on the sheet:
11,5V unloaded
AWG14/1,5mm2
200mA/T
693-6200.2200 IEC Socket /w fuse holder
Bolt on using self-securing nuts and M3x8mm machine screws
Bolt on using self-tapper UTS No4 6.5mm (1/4")

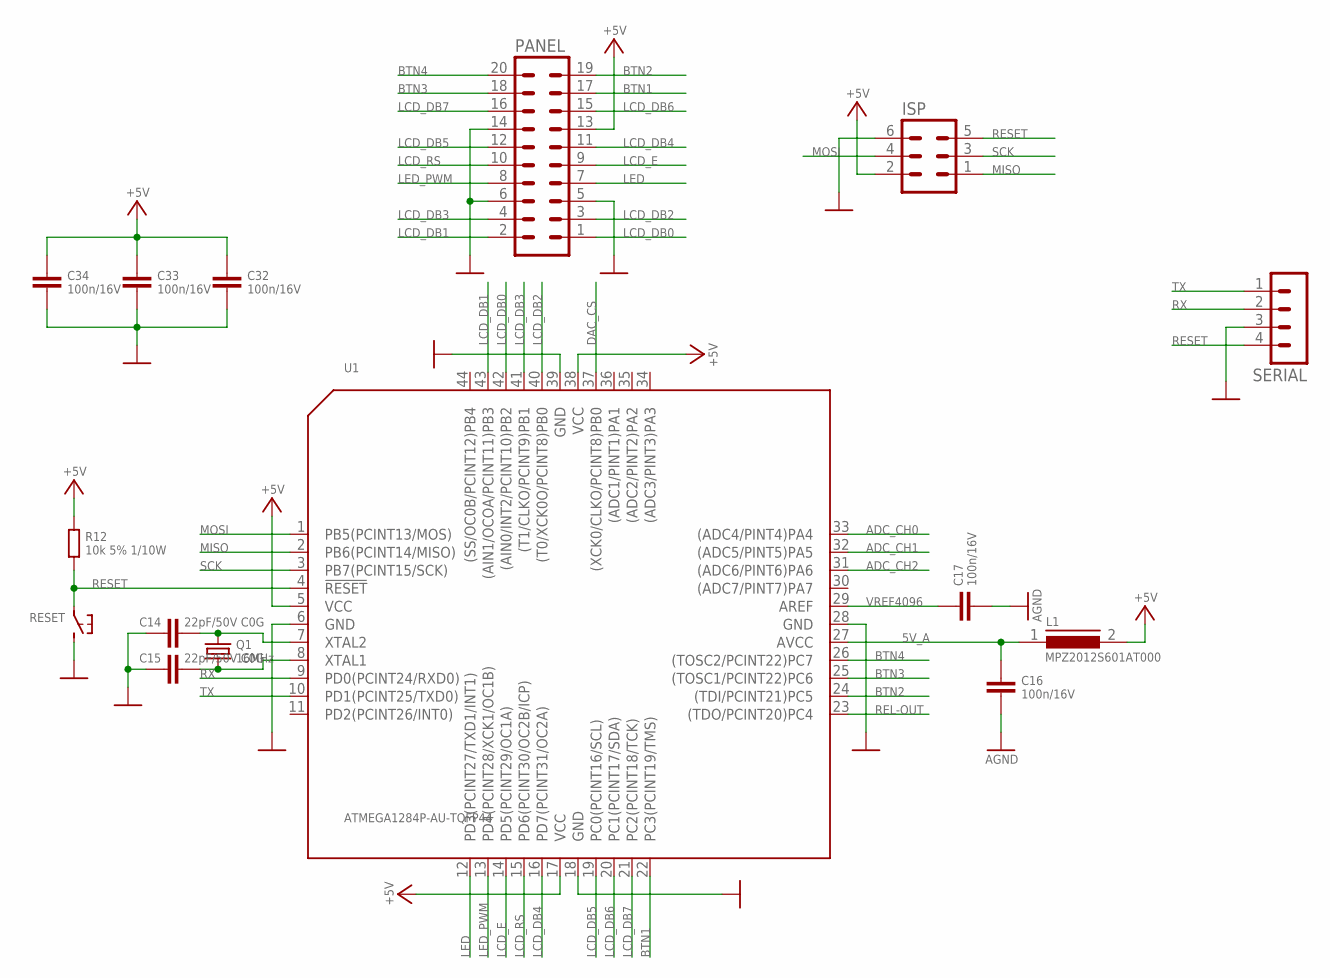
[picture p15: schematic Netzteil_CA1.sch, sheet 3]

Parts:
C14, C15: 22pF/50V C0G; 0805
C16, C17, C32, C33, C34: 100n/16V; 0805
ISP: ML6
L1: MPZ2012S601AT000; C0805K
PANEL: MA10-2
Q1: 16MHz; Q-5X3.2MM-TXC-7A.SERIES
R12: 10k 5% 1/10W; C0805K
RESET: TS1B3F-10XX; B3F-10XX
SERIAL: MA04-1
U1: ATMEGA1284P-AU-TQFP44; TQFP44-0.8-9.6X9.6MM

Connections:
5V_A: C16.1, L1.1, U1.27 (AVCC); also elsewhere on the board
+5V: C32.1, C33.1, C34.1, ISP.2, L1.2, PANEL.13, R12.1, U1.5 (VCC), U1.17 (VCC), U1.38 (VCC); also elsewhere on the board
ADC_CH0: U1.33 ((ADC4/PINT4)PA4); also elsewhere on the board
ADC_CH1: U1.32 ((ADC5/PINT5)PA5); also elsewhere on the board
ADC_CH2: U1.31 ((ADC6/PINT6)PA6); also elsewhere on the board
AGND: C16.2, C17.2; also elsewhere on the board
BTN1: PANEL.17, U1.22 (PC3(PCINT19/TMS))
BTN2: PANEL.19, U1.24 ((TDI/PCINT21)PC5)
BTN3: PANEL.18, U1.25 ((TOSC1/PCINT22)PC6)
BTN4: PANEL.20, U1.26 ((TOSC2/PCINT22)PC7)
DAC_CS: U1.37 ((XCK0/CLKO/PCINT8)PB0); also elsewhere on the board
LCD_DB0: PANEL.1, U1.42 ((AIN0/INT2/PCINT10)PB2)
LCD_DB1: PANEL.2, U1.43 ((AIN1/OCOA/PCINT11)PB3)
LCD_DB2: PANEL.3, U1.40 ((T0/XCK0O/PCINT8)PB0)
LCD_DB3: PANEL.4, U1.41 ((T1/CLKO/PCINT9)PB1)
LCD_DB4: PANEL.11, U1.16 (PD7(PCINT31/OC2A))
LCD_DB5: PANEL.12, U1.19 (PC0(PCINT16/SCL))
LCD_DB6: PANEL.15, U1.20 (PC1(PCINT17/SDA))
LCD_DB7: PANEL.16, U1.21 (PC2(PCINT18/TCK))
LCD_E: PANEL.9, U1.14 (PD5(PCINT29/OC1A))
LCD_RS: PANEL.10, U1.15 (PD6(PCINT30/OC2B/ICP))
LED: PANEL.7, U1.12 (PD3(PCINT27/TXD1/INT1))
LED_PWM: PANEL.8, U1.13 (PD4(PCINT28/XCK1/OC1B))
MISO: ISP.1, U1.2 (PB6(PCINT14/MISO))
MOSI: ISP.4, U1.1 (PB5(PCINT13/MOS)); also elsewhere on the board
unnamed: C14.2, Q1.2, U1.7 (XTAL2)
unnamed: C15.2, Q1.1, U1.8 (XTAL1)
REL-OUT: U1.23 ((TDO/PCINT20)PC4); also elsewhere on the board
RESET: ISP.5, R12.2, RESET.1, SERIAL.4, U1.4 (!RESET)
RX: SERIAL.2, U1.9 (PD0(PCINT24/RXD0))
SCK: ISP.3, U1.3 (PB7(PCINT15/SCK)); also elsewhere on the board
TX: SERIAL.1, U1.10 (PD1(PCINT25/TXD0))
VREF4096: C17.1, U1.29 (AREF); also elsewhere on the board
VSS: C14.1, C15.1, C32.2, C33.2, C34.2, ISP.6, PANEL.5, PANEL.6, PANEL.14, RESET.3 (2), SERIAL.3, U1.6 (GND), U1.18 (GND), U1.28 (GND), U1.39 (GND); also elsewhere on the board

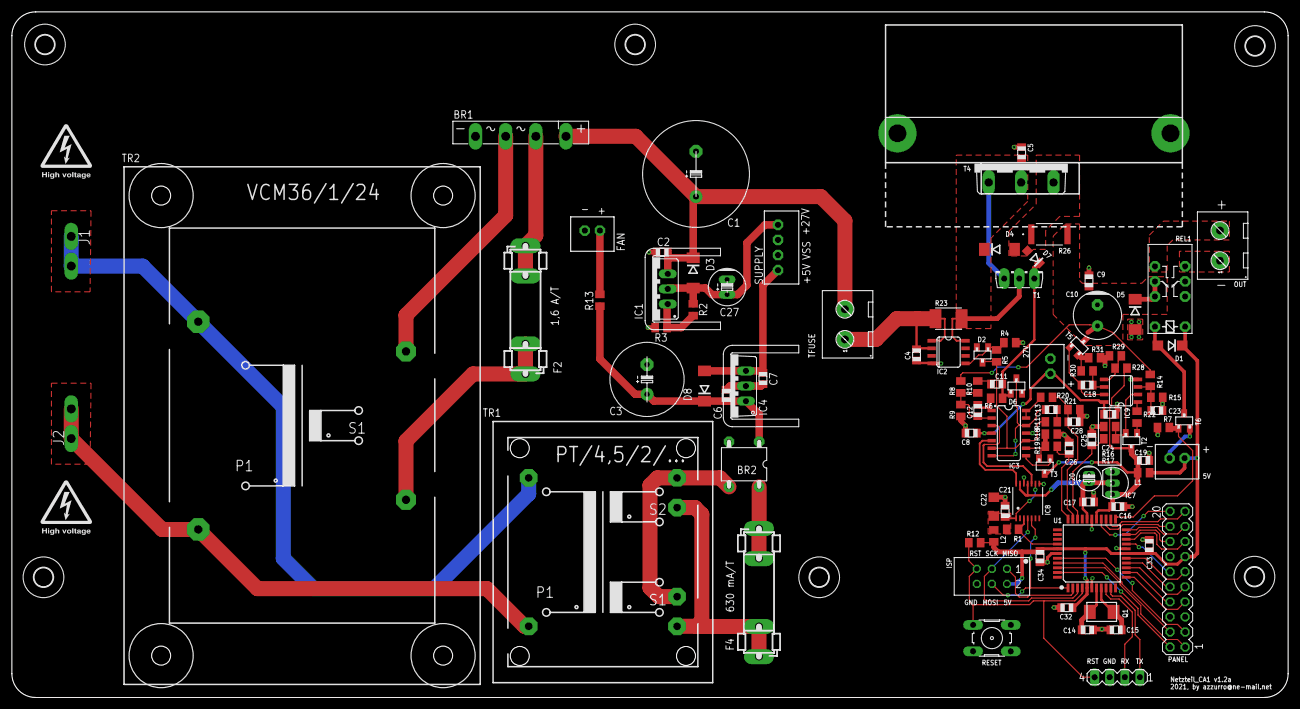
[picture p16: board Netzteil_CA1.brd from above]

Board: 2 copper layers, 215.0 x 115.5 mm, 115 parts (0 on the bottom side), 80 nets.

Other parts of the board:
U$10: CASE-Z17
U$18: IEC-C14-FUSED-6200.2200
U$21: FAN60X25

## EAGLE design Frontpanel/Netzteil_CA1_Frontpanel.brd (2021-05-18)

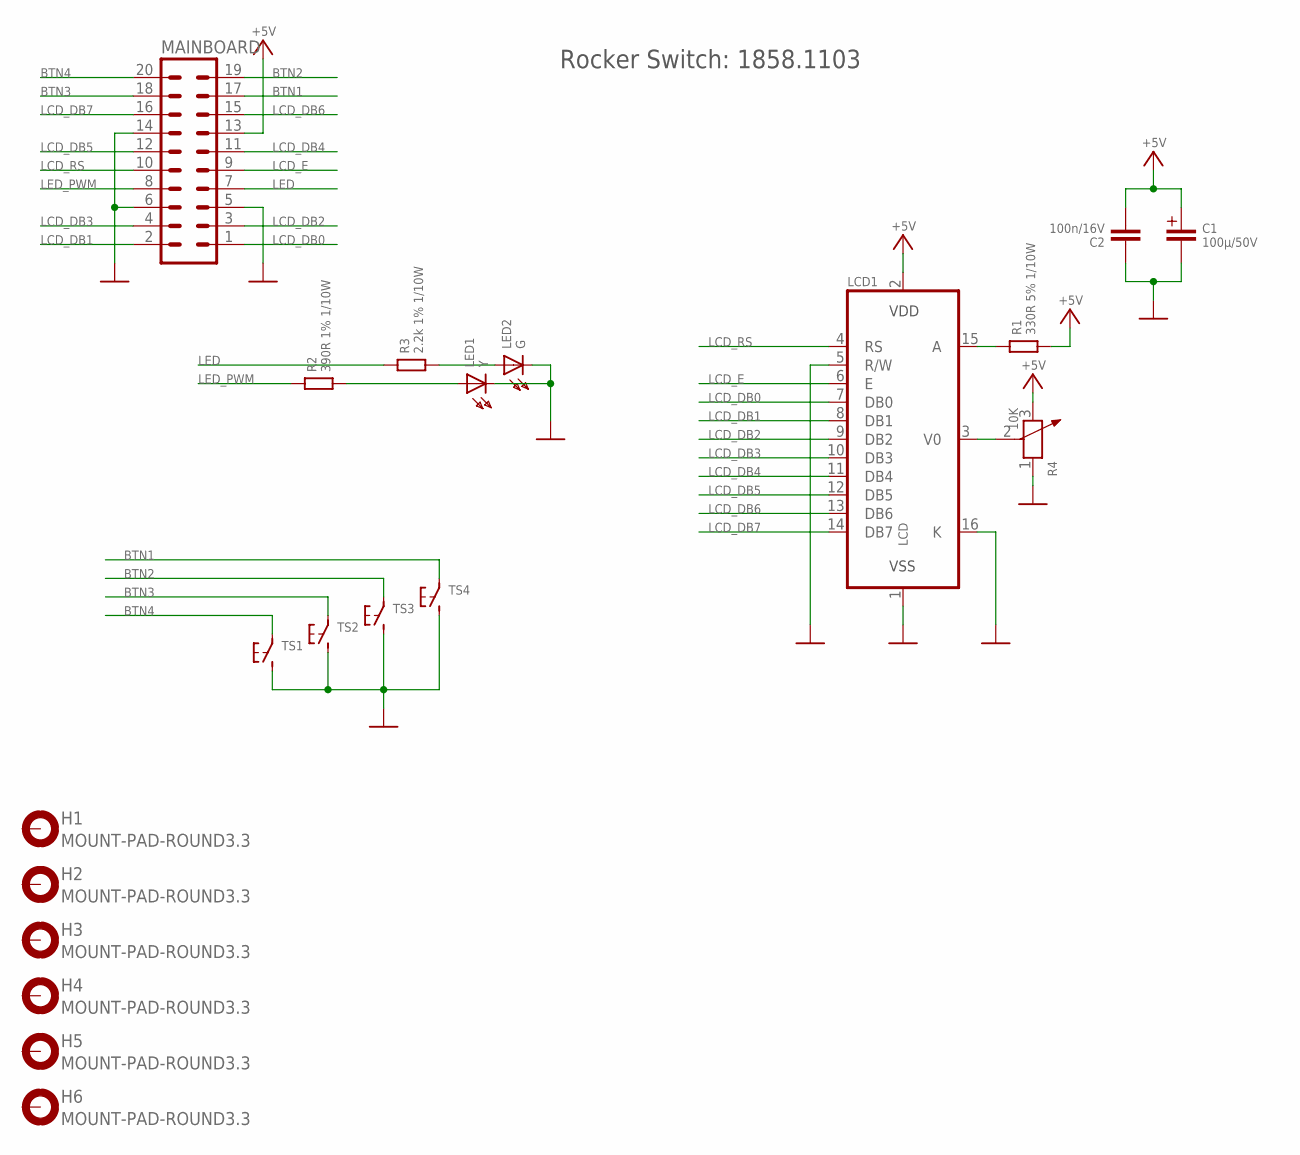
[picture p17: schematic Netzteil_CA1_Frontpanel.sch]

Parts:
C1: 100µ/50V; C+/3.5/8
C2: 100n/16V; 0805
H1, H2, H3, H4, H5, H6: MOUNT-PAD-ROUND3.3; 3,3-PAD
LCD1: LCD; DISPLAYTECH-204C
LED1: Y; LED0805
LED2: G; LED0805
MAINBOARD: MA10-2
R1: 330R 5% 1/10W; C0805K
R2: 390R 1% 1/10W; C0805K
R3: 2.2k 1% 1/10W; C0805K
R4: 10K; ADJR3-7.0X7.0X5.0MM
TS1, TS2, TS3, TS4: TS1B3F-10XX; B3F-10XX

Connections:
+5V: C1.+, C2.2, LCD1.2 (VDD), MAINBOARD.13, R1.2, R4.3
BTN1: MAINBOARD.17, TS4.1
BTN2: MAINBOARD.19, TS3.1
BTN3: MAINBOARD.18, TS2.1
BTN4: MAINBOARD.20, TS1.1
LCD_DB0: LCD1.7 (DB0), MAINBOARD.1
LCD_DB1: LCD1.8 (DB1), MAINBOARD.2
LCD_DB2: LCD1.9 (DB2), MAINBOARD.3
LCD_DB3: LCD1.10 (DB3), MAINBOARD.4
LCD_DB4: LCD1.11 (DB4), MAINBOARD.11
LCD_DB5: LCD1.12 (DB5), MAINBOARD.12
LCD_DB6: LCD1.13 (DB6), MAINBOARD.15
LCD_DB7: LCD1.14 (DB7), MAINBOARD.16
LCD_E: LCD1.6 (E), MAINBOARD.9
LCD_RS: LCD1.4 (RS), MAINBOARD.10
LED: MAINBOARD.7, R3.1
LED_PWM: MAINBOARD.8, R2.1
unnamed: LCD1.3 (V0), R4.2
unnamed: LCD1.15 (A), R1.1
unnamed: LED2.A, R3.2
unnamed: LED1.A, R2.2
VSS: C1.-, C2.1, LCD1.1 (VSS), LCD1.5 (R/W), LCD1.16 (K), LED1.C, LED2.C, MAINBOARD.5, MAINBOARD.6, MAINBOARD.14, R4.1, TS1.3 (2), TS2.3 (2), TS3.3 (2), TS4.3 (2)

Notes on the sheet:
Rocker Switch: 1858.1103

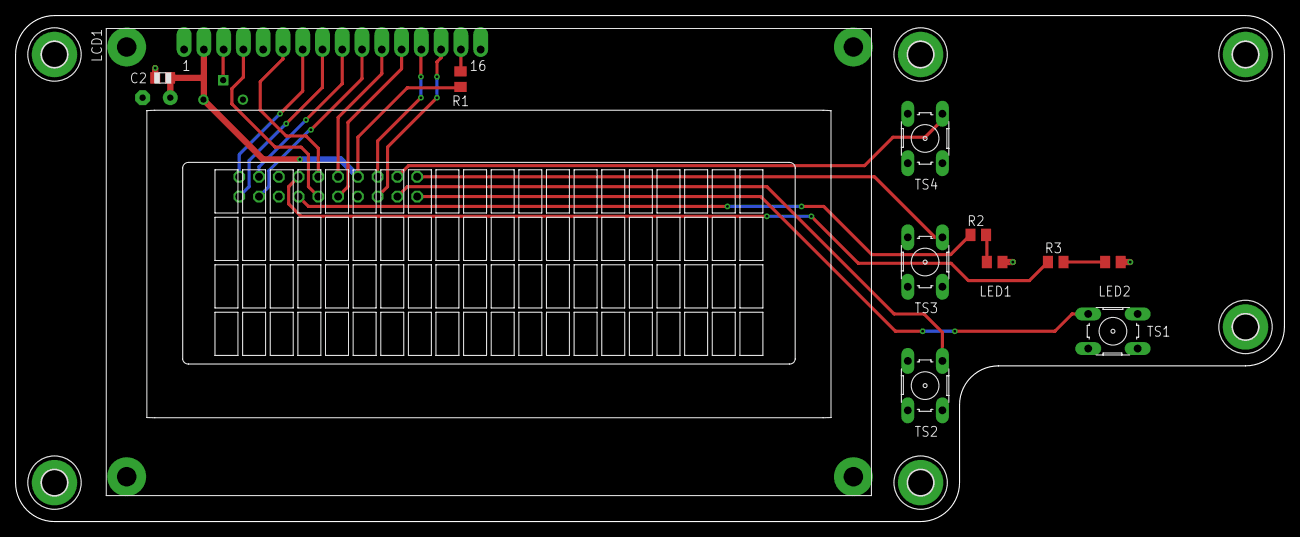
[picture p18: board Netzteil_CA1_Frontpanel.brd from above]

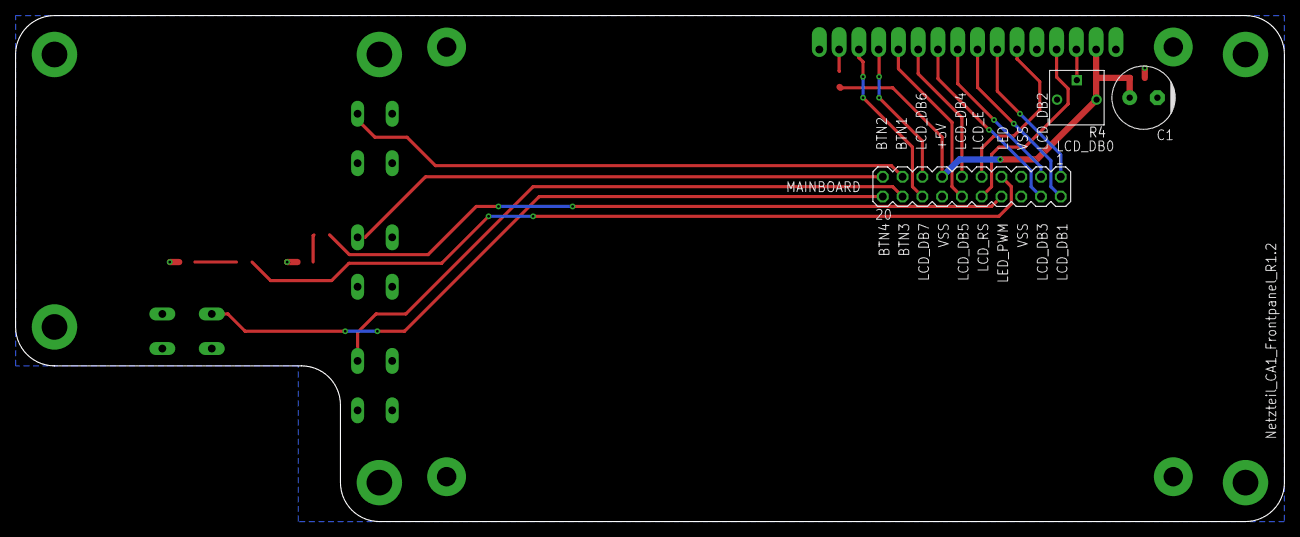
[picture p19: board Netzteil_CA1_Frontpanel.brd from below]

Board: 2 copper layers, 163.0 x 65.0 mm, 20 parts (3 on the bottom side), 22 nets.

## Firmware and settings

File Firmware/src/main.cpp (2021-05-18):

#include <Arduino.h>
#include <EEPROM.h>
#include <pins.h>
#include <config.h>

#include <AVRFunctional.h>
#include <RedirectPrintf.h>
#include <ButtonDebouncer.h>

#include <LiquidCrystal.h>
#include <dnxMCP4922.h>

#include <DACFunctions.h>
#include <HomeMenu.h>
#include <DisplayFunctions.h>
#include <ButtonFunctions.h>
#include <ADCFunctions.h>

LiquidCrystal LCD(LCD_RS_PIN, LCD_EN_PIN, LCD_DB0_PIN, LCD_DB1_PIN, LCD_DB2_PIN, LCD_DB3_PIN,LCD_DB4_PIN, LCD_DB5_PIN, LCD_DB6_PIN, LCD_DB7_PIN);

uint16_t currentCalibrationStep = 0;
uint32_t calibrationADCwaitMillis = 0;
uint16_t calibrationValues[DAC_V_STEPS] = { 0, };
uint8_t calibrationPercentage = 0;
uint8_t calibrationPercentage_prev = 0;

uint32_t selfTestWaitMillis = 0;

ButtonDebouncer ButtonUp;
ButtonDebouncer ButtonEnter;
ButtonDebouncer ButtonDown;
ButtonDebouncer ButtonOutput;

uint32_t lastADCupdateMillis = 0;

uint16_t adcVoltageRead[ADC_AVERAGING] = { 0 };
uint16_t adcCurrentRead[ADC_AVERAGING] = { 0 };
uint16_t adcOvervoltage[ADC_AVERAGING] = { 0 };

uint16_t adcVoltageReadAverage = 0;
uint16_t adcCurrentReadAverage = 0;
uint16_t adcOvervoltageAverage = 0;

uint16_t adcVoltageReadAverage_prev = 0;
uint16_t adcCurrentReadAverage_prev = 0;
uint16_t adcOvervoltageAverage_prev = 0;

bool adcVoltageReadAverageChanged = false;
bool adcCurrentReadAverageChanged = false;
bool adcOvervoltageAverageChanged = false;

uint8_t adcSampleIndex = 0;

uint16_t displayVoltageRead;
uint16_t displayCurrentRead;

bool OutputEnabled;

uint8_t initIndicator[9] = {'d', 'n', 'x', 'p', 's', 'u', 'c', 'a', '1'};

void loadSettings();
void initPins();
void processADC();
void setStartupValues(uint16_t voltage, uint16_t current);
void processCalibration();
void processSelfTest();

void setup()
{
	PrintfBegin(&Serial);
	analogReference(EXTERNAL);

	currentOpMode = OpMode::SELF_TEST_START;

	initButtons();
	initPins();

	loadSettings();

	setStartupValues(VOLTAGE_LOWER_LIMIT, CURRENT_UPPER_LIMIT);
	initDAC(VOLTAGE_LOWER_LIMIT, CURRENT_UPPER_LIMIT);
	initDisplay();
}

void loop()
{
	processSelfTest();
	processADC();
	UpdateDisplayRead();
	processCursor();
	processButtons();
	processCalibration();
}

void processSelfTest()
{
	if (currentOpMode == OpMode::SELF_TEST_START)
	{
		if (digitalRead(BUTTON_ENTER_PIN) == LOW && digitalRead(BUTTON_OUTPUT_PIN) == LOW)
		{
			currentOpMode = OpMode::SELF_TEST_COMPLETED;
			return;
		}

		SetDACVoltageRaw((DAC_V_UPPER_LIMIT / 4) * 0);
		selfTestWaitMillis = millis();
		currentOpMode = OpMode::SELF_TEST_PHASE1;

		LCD.clear();
		LCD.setCursor(0, 0);
		LCD.print(PRODUCT_FAMILY);
		LCD.print("-");
		LCD.print(PRODUCT_NAME);
		LCD.print(" SW V");
		LCD.print(FW_MAJOR);
		LCD.print(".");
		LCD.print(FW_MINOR);
		LCD.print(".");
		LCD.print(FW_PATCH);

		displayMessage("Startup self-test", MessageVAlignment::MIDDLE);		
	}
	else if (currentOpMode == OpMode::SELF_TEST_PHASE1 && selfTestWaitMillis + (ADC_POLL_INTERVAL * ADC_AVERAGING * 2) < millis())
	{
		uint16_t measuredVoltage = adcVoltageReadAverage * ADC_VREF * ADC_INPUT_VOLTAGE_DIVIDER / ADC_BITS;
		uint16_t setVoltage = (((DAC_V_UPPER_LIMIT / 4) * 0) * DAC_VREF * GAIN_V_DAC * GAIN_V_CONTROL_LOOP) / DAC_BITS;

		LOG("phase 1 self-test measured: %u, set: %u\r\n", measuredVoltage, setVoltage);

		if (adcCurrentReadAverage < 15)
		{
			LOG("current ok!\r\n");
		}
		else
		{
			lastErrorIndex++;
			errors[lastErrorIndex] = FailureReason::SELF_TEST_PHASE1_CURRENT;
			currentOpMode = OpMode::FAILED;
		}

		if (measuredVoltage >= 0 && measuredVoltage < setVoltage + 50)
		{
			LOG("voltage ok!\r\n");
			SetDACVoltageRaw((DAC_V_UPPER_LIMIT / 4) * 1);
			selfTestWaitMillis = millis();
			currentOpMode = OpMode::SELF_TEST_PHASE2;
			LCD.setCursor(0, 2);
			LCD.write(byte(4));
			LCD.write(byte(4));
			LCD.write(byte(4));
			LCD.write(byte(4));
		}
		else
		{
			lastErrorIndex++;
			errors[lastErrorIndex] = FailureReason::SELF_TEST_PHASE1_VOLTAGE;
			currentOpMode = OpMode::FAILED;
		}
		
	}
	else if (currentOpMode == OpMode::SELF_TEST_PHASE2 && selfTestWaitMillis + (ADC_POLL_INTERVAL * ADC_AVERAGING * 2) < millis())
	{
		uint16_t measuredVoltage = adcVoltageReadAverage * ADC_VREF * ADC_INPUT_VOLTAGE_DIVIDER / ADC_BITS;
		uint16_t setVoltage = (((DAC_V_UPPER_LIMIT / 4) * 1) * DAC_VREF * GAIN_V_DAC * GAIN_V_CONTROL_LOOP) / DAC_BITS;

		LOG("phase 2 self-test measured: %u, set: %u\r\n", measuredVoltage, setVoltage);

		if (adcCurrentReadAverage < 15)
		{
			LOG("current ok!\r\n");
		}
		else
		{
			lastErrorIndex++;
			errors[lastErrorIndex] = FailureReason::SELF_TEST_PHASE2_CURRENT;
			currentOpMode = OpMode::FAILED;
		}

		if (measuredVoltage > setVoltage - 200 && measuredVoltage < setVoltage + 200)
		{
			LOG("ok!\r\n");
			SetDACVoltageRaw((DAC_V_UPPER_LIMIT / 4) * 2);
			selfTestWaitMillis = millis();
			currentOpMode = OpMode::SELF_TEST_PHASE3;
			LCD.setCursor(4, 2);
			LCD.write(byte(4));
			LCD.write(byte(4));
			LCD.write(byte(4));
			LCD.write(byte(4));
		}
		else
		{
			lastErrorIndex++;
			errors[lastErrorIndex] = FailureReason::SELF_TEST_PHASE2_VOLTAGE;
			currentOpMode = OpMode::FAILED;
		}
	}
	else if (currentOpMode == OpMode::SELF_TEST_PHASE3 && selfTestWaitMillis + (ADC_POLL_INTERVAL * ADC_AVERAGING * 2) < millis())
	{
		uint16_t measuredVoltage = adcVoltageReadAverage * ADC_VREF * ADC_INPUT_VOLTAGE_DIVIDER / ADC_BITS;
		uint16_t setVoltage = (((DAC_V_UPPER_LIMIT / 4) * 2) * DAC_VREF * GAIN_V_DAC * GAIN_V_CONTROL_LOOP) / DAC_BITS;

		LOG("phase 3 self-test measured: %u, set: %u\r\n", measuredVoltage, setVoltage);

		if (adcCurrentReadAverage < 15)
		{
			LOG("current ok!\r\n");
		}
		else
		{
			lastErrorIndex++;
			errors[lastErrorIndex] = FailureReason::SELF_TEST_PHASE3_CURRENT;
			currentOpMode = OpMode::FAILED;
		}

		if (measuredVoltage > setVoltage - 200 && measuredVoltage < setVoltage + 200)
		{
			LOG("ok!\r\n");
			SetDACVoltageRaw((DAC_V_UPPER_LIMIT / 4) * 3);
			selfTestWaitMillis = millis();
			currentOpMode = OpMode::SELF_TEST_PHASE4;
			LCD.setCursor(8, 2);
			LCD.write(byte(4));
			LCD.write(byte(4));
			LCD.write(byte(4));
			LCD.write(byte(4));
		}
		else
		{
			lastErrorIndex++;
			errors[lastErrorIndex] = FailureReason::SELF_TEST_PHASE3_VOLTAGE;
			currentOpMode = OpMode::FAILED;
		}
	}
	else if (currentOpMode == OpMode::SELF_TEST_PHASE4 && selfTestWaitMillis + (ADC_POLL_INTERVAL * ADC_AVERAGING * 2) < millis())
	{
		uint16_t measuredVoltage = adcVoltageReadAverage * ADC_VREF * ADC_INPUT_VOLTAGE_DIVIDER / ADC_BITS;
		uint16_t setVoltage = (((DAC_V_UPPER_LIMIT / 4) * 3) * DAC_VREF * GAIN_V_DAC * GAIN_V_CONTROL_LOOP) / DAC_BITS;

		LOG("phase 4 self-test measured: %u, set: %u\r\n", measuredVoltage, setVoltage);

		if (adcCurrentReadAverage < 15)
		{
			LOG("current ok!\r\n");
		}
		else
		{
			lastErrorIndex++;
			errors[lastErrorIndex] = FailureReason::SELF_TEST_PHASE4_CURRENT;
			currentOpMode = OpMode::FAILED;
		}

		if (measuredVoltage > setVoltage - 200 && measuredVoltage < setVoltage + 200)
		{
			LOG("ok!\r\n");
			SetDACVoltageRaw((DAC_V_UPPER_LIMIT / 4) * 4);
			selfTestWaitMillis = millis();
			currentOpMode = OpMode::SELF_TEST_PHASE5;
			LCD.setCursor(12, 2);
			LCD.write(byte(4));
			LCD.write(byte(4));
			LCD.write(byte(4));
			LCD.write(byte(4));
		}
		else
		{
			lastErrorIndex++;
			errors[lastErrorIndex] = FailureReason::SELF_TEST_PHASE4_VOLTAGE;
			currentOpMode = OpMode::FAILED;
		}
	}
	else if (currentOpMode == OpMode::SELF_TEST_PHASE5 && selfTestWaitMillis + (ADC_POLL_INTERVAL * ADC_AVERAGING * 2) < millis())
	{
		uint16_t measuredVoltage = adcVoltageReadAverage * ADC_VREF * ADC_INPUT_VOLTAGE_DIVIDER / ADC_BITS;
		uint16_t setVoltage = (((DAC_V_UPPER_LIMIT / 4) * 4) * DAC_VREF * GAIN_V_DAC * GAIN_V_CONTROL_LOOP) / DAC_BITS;

		LOG("phase 5 self-test measured: %u, set: %u\r\n", measuredVoltage, setVoltage);

		SetDACVoltage(VOLTAGE_LOWER_LIMIT);

		if (adcCurrentReadAverage < 15)
		{
			LOG("current ok!\r\n");
		}
		else
		{
			lastErrorIndex++;
			errors[lastErrorIndex] = FailureReason::SELF_TEST_PHASE5_CURRENT;
			currentOpMode = OpMode::FAILED;
		}

		if (measuredVoltage > setVoltage - 1000 && measuredVoltage < setVoltage + 200)
		{
			LOG("ok!\r\n");
			currentOpMode = OpMode::SELF_TEST_COMPLETED;
		}
		else
		{
			lastErrorIndex++;
			errors[lastErrorIndex] = FailureReason::SELF_TEST_PHASE5_VOLTAGE;
			currentOpMode = OpMode::FAILED;
		}
	}
	else if (currentOpMode == OpMode::SELF_TEST_COMPLETED)
	{
		currentOpMode = OpMode::REGULAR;
		LCD.setCursor(16, 2);
		LCD.write(byte(4));
		LCD.write(byte(4));
		LCD.write(byte(4));
		LCD.write(byte(4));
		delay((ADC_POLL_INTERVAL * ADC_AVERAGING * 2));
		displayMainScreen();
		UpdateDisplay();
	}
	else if (currentOpMode == OpMode::FAILED)
	{
		SetDACVoltage(DAC_V_LOWER_LIMIT);
		digitalWrite(REL_OUT_PIN, LOW);
		digitalWrite(LED_OUTPUT_PIN, LOW);

		LCD.setCursor(0, 2);
		LCD.print("                    ");
		LCD.setCursor(7, 2);
		LCD.print("FAILED");
		LCD.setCursor(0, 3);
		LCD.print("Error(s): ");

		if (lastErrorIndex == -1 || lastErrorIndex >= static_cast<int8_t>(sizeof(errors)))
		{
			LCD.print("unknown");
		}
		else
		{
			for (uint8_t n = 0; n <= lastErrorIndex; n++)
			{
				LCD.print(static_cast<uint8_t>(errors[n]));
				if (n != lastErrorIndex)
					LCD.print(", ");
			}
		}

		while(1)
		{
			digitalWrite(LED_STATUS_PIN, HIGH);
			delay(300);
			digitalWrite(LED_STATUS_PIN, LOW);
			delay(300);
		}		

	}
}

void loadSettings()
{
	// load init indicator from EEPROM
	uint8_t bufCompareInitIndicator[9];
	EEPROM.get(EEPROM_ADDR_INIT_INDICATOR, bufCompareInitIndicator);
	
	// load settings if init indicator matches, otherwise save default settings and init indicator to EEPROM
	if (memcmp(bufCompareInitIndicator, initIndicator, sizeof(bufCompareInitIndicator)) == 0)
	{
		EEPROM.get(EEPROM_ADDR_CALIBRATION, calibrationValues);
	}
	else
	{
		EEPROM.put(EEPROM_ADDR_CALIBRATION, calibrationValues);
		EEPROM.put(EEPROM_ADDR_INIT_INDICATOR, initIndicator);
	}	
}

void processCalibration()
{
	if (currentOpMode != OpMode::CALIBRATION_START &&
		currentOpMode != OpMode::CALIBRATING &&
		currentOpMode != OpMode::CALIBRATING_WAIT_SETTLE && 
		currentOpMode != OpMode::CALIBRATION_FINISHED_WAITING && 
		currentOpMode != OpMode::CALIBRATION_FINISHED_EXIT)
		{
			return;
		}
		

	if (currentCalibrationStep == DAC_V_STEPS && currentOpMode == OpMode::CALIBRATING)	// finished
	{
		LOG("Calibration completed\r\n");
		for (uint16_t n = 0; n < DAC_V_STEPS; n++)
		{
			Serial.print(calibrationValues[n]);
			Serial.print(", ");
		}
		Serial.println("");
		SetDACVoltage(VoltageMenu_E.Digit * 1000 + VoltageMenu_z.Digit * 100);
		LCD.clear();
		displayMessage("Calibration finished\r\nPress any key\r\nto continue", MessageVAlignment::MIDDLE);
		currentOpMode = OpMode::CALIBRATION_FINISHED_WAITING;
	}
	else if (currentCalibrationStep == DAC_V_STEPS && currentOpMode == OpMode::CALIBRATION_FINISHED_WAITING)
	{

	}
	else if (currentCalibrationStep == DAC_V_STEPS && currentOpMode == OpMode::CALIBRATION_FINISHED_EXIT)
	{
		EEPROM.put(EEPROM_ADDR_CALIBRATION, calibrationValues);
		currentOpMode = OpMode::REGULAR;
		currentCalibrationStep = 0;
		SelectedMenu = &VoltageMenu;
		displayMainScreen();
	}
	else
	{
		if (currentOpMode == OpMode::CALIBRATION_START)
		{
			LOG("CALIBRATION_START: set DAC to lower limit\r\n");
			LOG("CALIBRATING_START: wait for output voltage to settle\r\n");
			SetDACVoltageRaw(DAC_V_LOWER_LIMIT);
			currentCalibrationStep = 0;
			currentOpMode = OpMode::CALIBRATING_WAIT_SETTLE;
			calibrationADCwaitMillis = millis();
		}
		else if (currentOpMode == OpMode::CALIBRATING_WAIT_SETTLE)
		{
			if (calibrationADCwaitMillis + (ADC_POLL_INTERVAL * ADC_AVERAGING * 8) < millis())
			{
				LOG("CALIBRATING_WAIT_SETTLE: done waiting\r\n");
				currentOpMode = OpMode::CALIBRATING;
				calibrationADCwaitMillis = millis();
			}
		}
		else if (currentOpMode == OpMode::CALIBRATING)
		{
			// if (calibrationADCwaitMillis + (ADC_POLL_INTERVAL) < millis())
			if (calibrationADCwaitMillis + (ADC_POLL_INTERVAL * ADC_AVERAGING * 3) < millis())
			{
				calibrationValues[currentCalibrationStep] = adcCurrentReadAverage;
				calibrationPercentage = (currentCalibrationStep * 100) / (DAC_V_STEPS - 1);
				if (calibrationPercentage != calibrationPercentage_prev)
				{
					calibrationPercentage_prev = calibrationPercentage;
					LCD.setCursor(9, 3);
					LCD.print(calibrationPercentage);
					LCD.print("%");
				}
				LOG("CALIBRATING: [%03u%%] index %u, val %u\r\n", calibrationPercentage, currentCalibrationStep, adcCurrentReadAverage);

				SetDACVoltageRaw(DAC_V_LOWER_LIMIT + (DAC_V_STEPSIZE * currentCalibrationStep));
				currentCalibrationStep++;
				calibrationADCwaitMillis = millis();
			}
		}
	}
}

void initPins()
{
	pinMode(BUTTON_UP_PIN, INPUT_PULLUP);
	pinMode(BUTTON_ENTER_PIN, INPUT_PULLUP);
	pinMode(BUTTON_DOWN_PIN, INPUT_PULLUP);
	pinMode(BUTTON_OUTPUT_PIN, INPUT_PULLUP);
	
	pinMode(LED_STATUS_PIN, OUTPUT);
	pinMode(LED_OUTPUT_PIN, OUTPUT);

	digitalWrite(LED_STATUS_PIN, LOW);
	digitalWrite(LED_OUTPUT_PIN, LOW);
	
	pinMode(REL_OUT_PIN, OUTPUT);
	digitalWrite(REL_OUT_PIN, LOW);
}

void setStartupValues(uint16_t voltage, uint16_t current)
{
	VoltageMenu_E.Digit = voltage / 1000;
	VoltageMenu_z.Digit = (voltage / 100) % 10;

	CurrentMenu_E.Digit = current / 1000;
	CurrentMenu_z.Digit = (current / 100) % 10;
	CurrentMenu_h.Digit = (current / 10) % 10;
	CurrentMenu_t.Digit = current % 10;
}

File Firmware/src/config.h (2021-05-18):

#ifndef config_h
	#define config_h

	#define EEPROM_ADDR_INIT_INDICATOR		0
	#define EEPROM_ADDR_CALIBRATION			9

	#define LCD_COLS						20
	#define LCD_ROWS						4

	#define DISPLAY_UPDATE_INVERVAL			500
	#define BUTTON_REPEAT_MENU_INTERVAL		500
	#define BUTTON_REPEAT_VALUE_INTERVAL	100

	// #define DAC_FAN_UPPER_LIMIT				255
	// #define DAC_FAN_LOWER_LIMIT				0

	#define DAC_V_LOWER_LIMIT				0
	#define DAC_V_UPPER_LIMIT				2500 // (Vout (max) in mV - VOUT_OFFSET_MV) / VOUT_GAIN

	#define VOLTAGE_UPPER_LIMIT				25000	// mV
	#define VOLTAGE_LOWER_LIMIT				0		// mV
	#define CURRENT_UPPER_LIMIT				1000	// mA
	#define CURRENT_LOWER_LIMIT				0		// mA

	#define DAC_I_LOWER_LIMIT				0
	#define DAC_I_UPPER_LIMIT				4000	//  500 bei 100mOhm Shunt, 4000 bei 800mOhm Shunt   Iout (max) in mA * 2 --- MAX4080T outputs e.g. 100mV for 50mA load so 1000mV upper limit will be 500mA Iout (max)
													// MAX4080F - Gain: 5 - 1A @ 0.1R Shunt = 0.1V * 5 (Gain) = 0.5V ---	1000mA Imax = DAC_I_UPPER_LIMIT 500
													//																		2000mA Imax = DAC_I_UPPER_LIMIT 1000
													//																		Formula:	DAC_I_UPPER_LIMIT = Imax / 2
													//																					Imax = DAC_I_UPPER_LIMIT * 2

	#define DAC_V_STARTUP_VALUE				DAC_V_LOWER_LIMIT
	#define DAC_I_STARTUP_VALUE				DAC_I_UPPER_LIMIT

	#define DAC_VREF						4096UL
	#define GAIN_V_DAC						2U	// 2x DAC internal Gain
	#define GAIN_V_CONTROL_LOOP				5U	// 5x Control loop Gain
	
	#define GAIN_I_DAC						1
	
	#define GAIN_I_CONTROL_LOOP				20U	// 5x Control loop Gain
	// #define GAIN_I_CONTROL_LOOP				20U	// 5x Control loop Gain
	// #define ADC_CURRENT_SHUNT_RESISTANCE	0.8f	// Ohm
	#define ADC_CURRENT_SHUNT_RESISTANCE	0.2f	// Ohm
	
	#define DAC_V_STEPSIZE					10

	#define DAC_I_STEPSIZE					4 // 1 bei 100mOhm Shunt, 4 bei 800mOhm Shunt
	#define DAC_MIN_SET_DELAY				100

	#define DAC_V_STEPS						((DAC_V_UPPER_LIMIT - DAC_V_LOWER_LIMIT) / DAC_V_STEPSIZE)
	// #define DAC_I_STEPS						((DAC_I_UPPER_LIMIT - DAC_I_LOWER_LIMIT) / DAC_I_STEPSIZE) + 1

	#define DAC_BITS						4096UL // 12 Bit
	// #define DAC_OFFSET						1		// MCP4922 step 0 of 4095 means first step (VREF/4096), not zero. So 0 would be 0,5mV for 2048mV VREF.

	#define ADC_VREF						4096UL
	#define ADC_BITS						1024UL

	// #define ADC_INPUT_VOLTAGE_DIVIDER		6U
	#define ADC_INPUT_VOLTAGE_DIVIDER		6.25f

	#define ADC_INPUT_CURRENT_DIVIDER		1U
	// #define ADC_V_READ_MULTIPLICATOR		(ADC_VREF * ADC_INPUT_VOLTAGE_DIVIDER / ADC_BITS)
	// #define ADC_I_READ_MULTIPLICATOR		(ADC_CURRENT_SHUNT_RESISTANCE * GAIN_I_CONTROL_LOOP * ADC_VREF * ADC_INPUT_CURRENT_DIVIDER / ADC_BITS)
	#define ADC_POLL_INTERVAL				100
	
	#define ADC_AVERAGING					4

	// #define ADC_TEENSY_VREF					2048
	// #define ADC_TEENSY_BITS					4096
	// #define ADC_TEENSY_POLL_INTERVAL		100
	// #define ADC_TEENSY_AVERAGING			32

	// #define ADC_CURRENT_GAIN				50		// Current shunt amplifier gain factor

	#define DEBOUNCE_INTERVAL				10

	// TM Temperature Monitor
	// #define TM_DIVIDER_VOLTAGE				15000
	// #define TM_DIVIDER_R1					681000
	// #define TM_DIVIDER_NTC_NOMINAL			100000
	// #define TM_DIVIDER_NTC_COEFFICIENT		4190

	// #define BUZZER_ENABLED
	// define DISPLAY_UPDATE_ON_ADC_UPDATE

#endif

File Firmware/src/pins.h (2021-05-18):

#ifndef pins_h
	#define pins_h

	// ##### Pin definitions

	#define DAC_CS							A0 //18
	
	#define BUTTON_DOWN_PIN					22
	#define BUTTON_UP_PIN					19
	#define BUTTON_ENTER_PIN				21
	#define BUTTON_OUTPUT_PIN				23
	#define LED_STATUS_PIN					12
	#define LED_OUTPUT_PIN					11
	#define LCD_RS_PIN						14
	#define LCD_EN_PIN						13
	#define LCD_DB0_PIN						2
	#define LCD_DB1_PIN						3
	#define LCD_DB2_PIN						0
	#define LCD_DB3_PIN						1
	#define LCD_DB4_PIN						15
	#define LCD_DB5_PIN						16
	#define LCD_DB6_PIN						17
	#define LCD_DB7_PIN						18
	#define REL_OUT_PIN						20

	#define ADC_CURRENT_READ_CH				A4 //A1	// onboard current sensing		### A1
	#define ADC_OVRCRNT_DET_CH				A5 //A2	// overcurrent detection		### A2
	#define ADC_VOLTAGE_READ_CH				A6
#endif

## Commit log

2019-07-12 initial release
    [BOM.xlsx, Netzteil_CA1.brd, Netzteil_CA1.sch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]
2019-07-12 move a via
    [Netzteil_CA1.brd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]
2019-07-12 correction of top soldermask
    [Netzteil_CA1.brd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]
2021-05-18 Update to 1.2a
    [BOM-v1.2.xlsx, BOM.xlsx, Netzteil_CA1.brd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]
2021-05-18 add STLs
    [button.stl, front_panel_CA1_R1.2_565-6883.stl]
